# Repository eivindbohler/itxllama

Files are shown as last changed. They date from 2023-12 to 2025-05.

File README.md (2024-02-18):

# ITX-Llama User's Guide
  
> **Note**  
> This document is still a work in progress.  
For feedback, suggestions, etc. - please add a post to the [Vogons thread][vogons-thread].

### Contents
- [Installing the SOM](#installing-the-som)
- [Jumper Configuration](#jumper-configuration)
  * [PS/2 and USB HID](#ps2-or-usb-hid)
  * [Line In](#line-in)
  * [Pi or Wavetable](#pi-or-wavetable)
- [Flashing the BIOS](#flashing-the-bios)
- [DOS](#dos)
  * [Mouse in DOS](#mouse-in-dos)
  * [Audio in DOS](#audio-in-dos)
- [Windows 98](#windows-98)
- [Windows 98 Drivers](#windows-98-drivers)
  * [TBPlus](#tbplus)
  * [USB](#usb)
  * [Crystal Audio](#crystal-audio)
  * [Ethernet](#ethernet)
- [Fans](#fans)
- [mt32-pi](#mt32-pi)

## Installing the SOM
When installing the Vortex86EX SOM, _carefully_ align the module as shown in the image below, and _gently_ push it down on the 64 pins.  
Note that the pins on the motherboard are quite thin and fragile, and if you misalign the SOM or use excessive force, they'll likely bend or break.  
Take your time, be careful and double-check the placement before proceeding further!
<p>
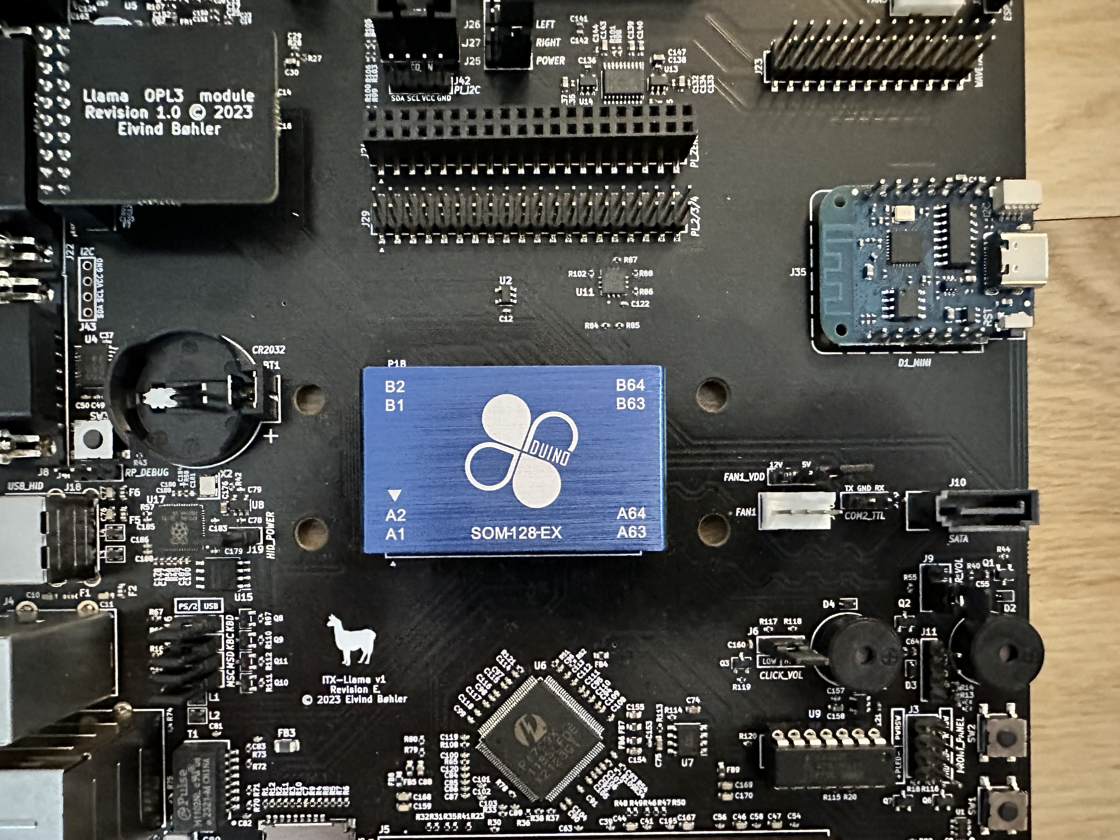
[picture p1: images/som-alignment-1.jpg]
SOM alignment
  
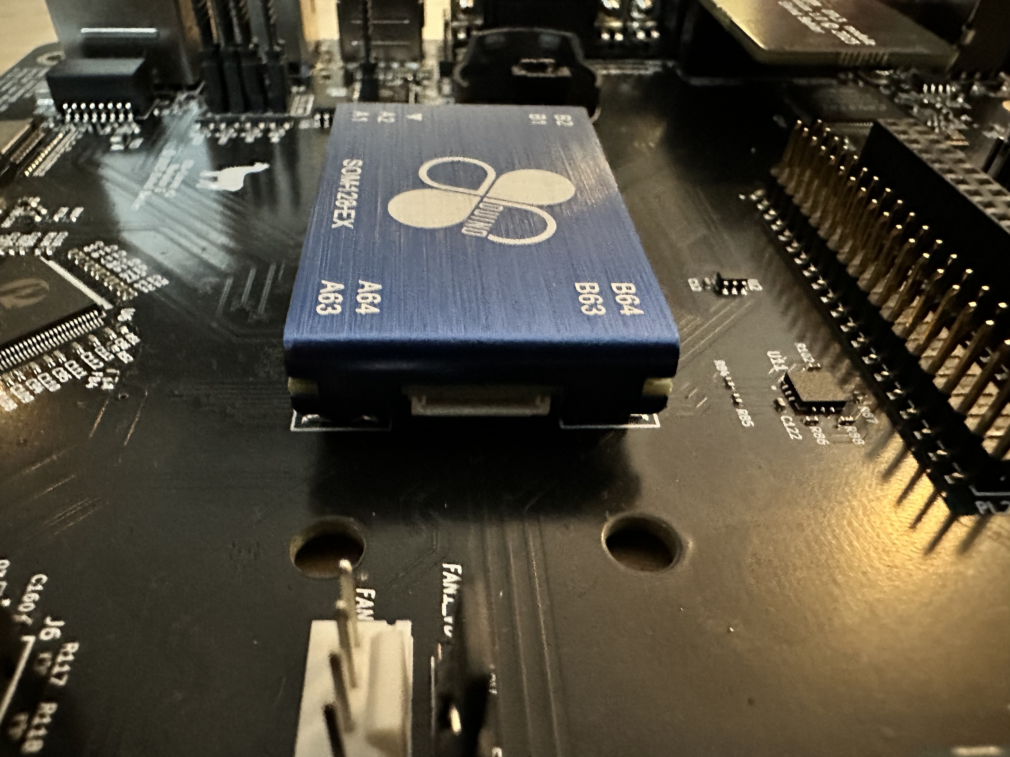
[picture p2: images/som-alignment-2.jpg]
SOM alignment
  
</p>

## Jumper Configuration
The board should come preinstalled with all the jumpers necessary.  
For changing the configuration, here's a quick walkthrough of the different jumpers and their functionality.

### PS/2 or USB HID
Jumpers: J7, J12, J15, J16
<p>
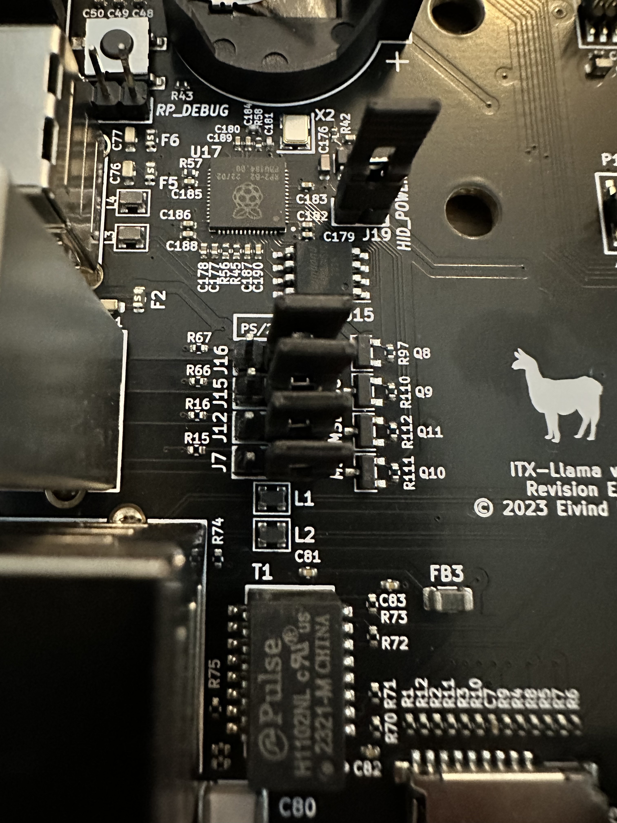
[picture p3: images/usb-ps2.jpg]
PS/2 configuration
  
</p>
If you want to use a real PS/2 keyboard connected to the purple PS/2 port, place the two topmost jumpers (J15 and J16) to the leftmost position ("PS/2"). For USB HID keyboard connected to one of the white USB ports (between the PS/2 and serial port), place the jumpers to the rightmost side ("USB").  
Same goes for PS/2 mouse and jumpers J7 and J12.

### Line In
Jumpers: J39, J40
<p>
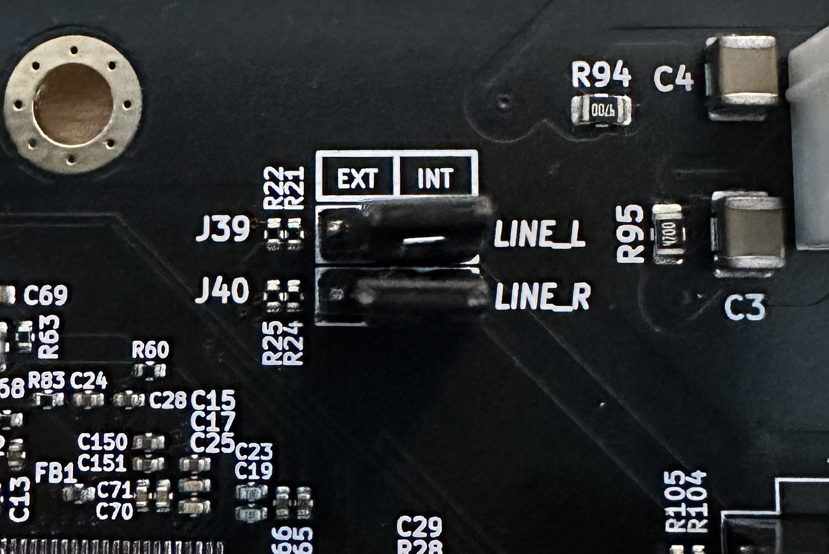
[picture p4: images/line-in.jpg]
Line In
  
</p>
If you want to use an external audio source connected to the blue 3.5mm jack port, place both jumpers to the leftmost position ("EXT").  
For using a Raspberry Pi Zero2 or Wavetable board as line-in to the sound card, place the two jumpers to the rightmost position ("INT").

### Pi or Wavetable
Jumpers: J25, J26, J27
<p>
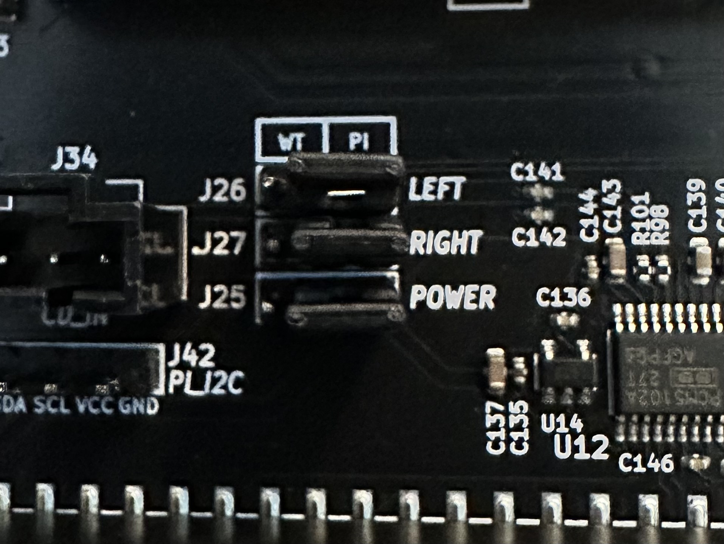
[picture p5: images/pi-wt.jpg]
PI/WT configuration
  
</p>
For using a Raspberry Pi (Zero2, 3 or 4) for converting MIDI to analog audio, place the three jumpers to the rightmost position ("PI").  
For using a wavetable board, place the jumpers to the leftmost position ("WT").

## Flashing the BIOS
If you've purchased the Vortex86EX system-on-module (SOM) from DMP, ICOP, etc - you need to flash the BIOS first.  
Since the BIOS that comes pre-installed on the SOM is set up for another pinout/configuration, the microSD card slot isn't availble yet, and you need to use a USB flash drive for this part.  
  
Format the flash drive with a DOS-bootable FAT16/32 partition and copy over the [ANYBIOS.EXE and ITXBIOS.ROM files](INITBIOS).  
Alternatively (and easier), just do a block-level transfer of the [INITBIOS.IMG](INITBIOS) file to the flash drive using [Balena Etcher][balena-etcher], `dd` or something similar.  
Then place the flash drive in one of the USB ports (the ones below the RJ45 port). Plug a USB keyboard in the other port. **Note**: at this point, a keyboard plugged into one of the two _HID-only (white)_ ports won't work, you need to use the ones below the RJ45 port!  
Power up the system, and hopefully you'll get a DOS prompt. From there just type:
```
anybios w itxbios.rom
```
Once done, shut down the computer, remove the flash drive and move the keyboard to one of the HID ports.

## DOS
Follow these instructions to set up DOS on a microSD card, SATA drive or USB flash drive:  
(Note: a SATA drive is faster, but this isn't that important in DOS. I recommend using a microSD card, because you'll be able to use the "clicker" feature to simulate the seeking sounds of an old spinning drive, if you're interested in that)
1. Turn off the system, insert a drive of choice.
2. Boot the system, press ESC to bring up the boot menu.
3. Choose the Virtual Floppy drive.
4. Run `fdisk`, select and partition the drive however you want. Make sure to have at least one primary partition, and make it `Active`.
5. Quit fdisk and reboot the system.
6. Once again, boot the system using the Virtual Floppy drive.
7. Run `fdisk /mbr` to write the correct MBR bytes to the new drive.
8. Run `format c: /s` to format the new drive and copy over the necessary system files.
9. Shut down the machine and remove the drive.
10. Copy over DOS and whatever else you want from a modern computer.

### Mouse in DOS
Use [CuteMouse (CTMOUSE.EXE)](DOS-utils).

### Audio in DOS
The Crystal CS4237B sound chip is automatically initialized and configured from the BIOS, so you don't need any drivers in DOS.  
If you wish to change any of the mixer settings, use [CWDMIX.EXE](DOS-Utils).

## Windows 98
Before proceeding, I'd _strongly_ recommend using a SATA drive for Windows 98, as the performance is noticably better than running from an SD card or USB drive.  
  
Download Windows 98 SE from [WinWorldPC][winworldpc-win98]. Product keys are there as well.  
  
Prepare a bootable DOS drive (see the [DOS](#dos) section above), copy the `WIN98` folder over to the drive and run the `SETUP.EXE` from within.

Note: at some point during the installation, you'll get a crash. This is due to the IDE driver being incompatible with the Vortex86EX's IDE controller.  
Reboot, and choose "Safe Mode". From within Win98, install the [TBPLUS](WIN98-drivers/TBPLUS) drivers from R. Loew and then reboot again and complete the installation.  
  
An easier way is to install Windows 98 SE is using a [version I've prepared](WIN98) which has the IDE drivers "slipstreamed" (meaning that Windows will use the updated drivers automatically).

## Windows 98 Drivers

### TBPlus
If you installed the TBPlus drivers during the Windows 98 installation, or used the slipstreamed Windows 98 installer you're all set. If not, install the [TBPlus drivers](WIN98-drivers/TBPLUS).

### USB
In the BIOS Settings, you can choose to have USB flash drives appear to the system as fixed disks.  
With this setting enabled, they'll show up as regular hard drives in DOS and Windows.  
If you turn this setting _off_, you can use flash drives as removable storage in Windows 98. Use [nusb36e.exe](WIN98-drivers/USB) to install the required drivers.

### Crystal Audio
Run `SETUP.EXE` from the [Crystal Audio](WIN98-drivers/CWD-v286-1998-itx-llama) driver folder.

### Ethernet
From Device Manager, find the Ethernet device and install the [RDC R6040 driver](WIN98-drivers/r6040_win98).

## Fans
The Vortex86EX SOM doesn't draw much power, and shouldn't require active cooling if running at or below 300 MHz.  
If you do wish to add one or more fans, the motherboard has three separately controllable 4-pin PWM fan connectors:
<p>
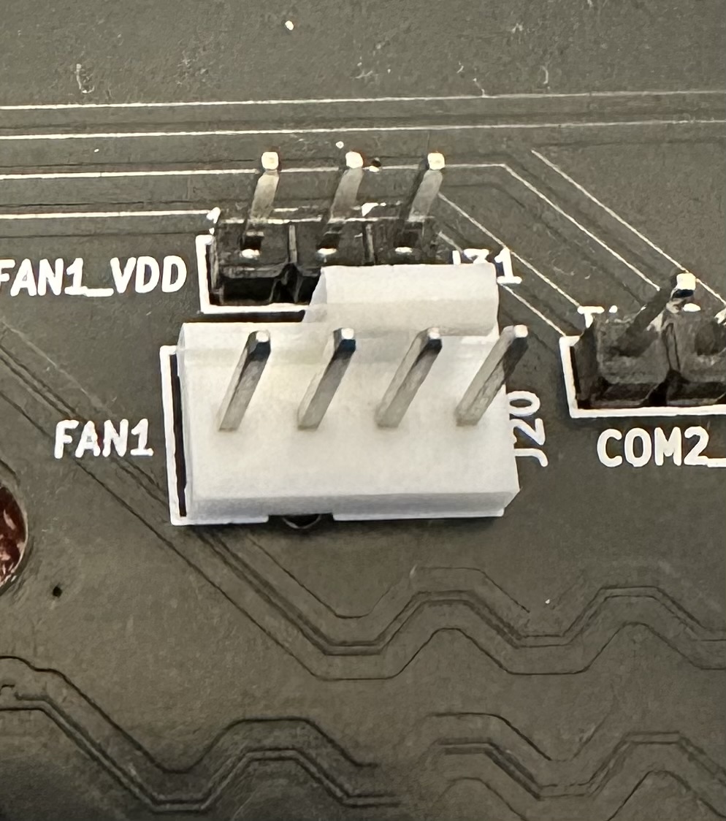
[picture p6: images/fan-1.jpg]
Fan header
  
</p>
Simply connect a modern 4-pin fan to one of these headers, and set the corresponding jumper to either 5V or 12V:
<p>
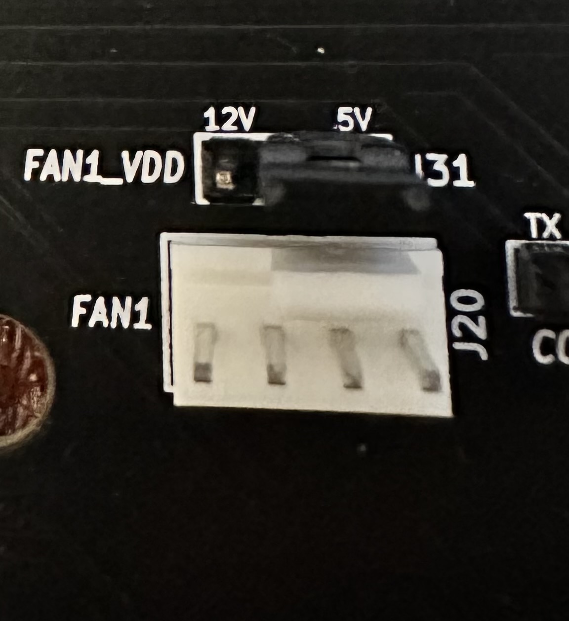
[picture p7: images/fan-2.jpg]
Fan configuration
  
</p>

Note: Take care **not** to supply 12V to a 5V fan - you'll likely fry it.

## mt32-pi
If you want to use a Raspberry Pi as an MT-32 or MIDI synthesizer, download and install the [mt32-pi][mt32-pi] bare-metal software on the Pi, and plug it into the motherboard.  
If you go with a Pi Zero 2 (the easiest and cheapest option), make sure to solder the 40-pin connector to the _bottom_ side of the Pi, as seen here:
<p>
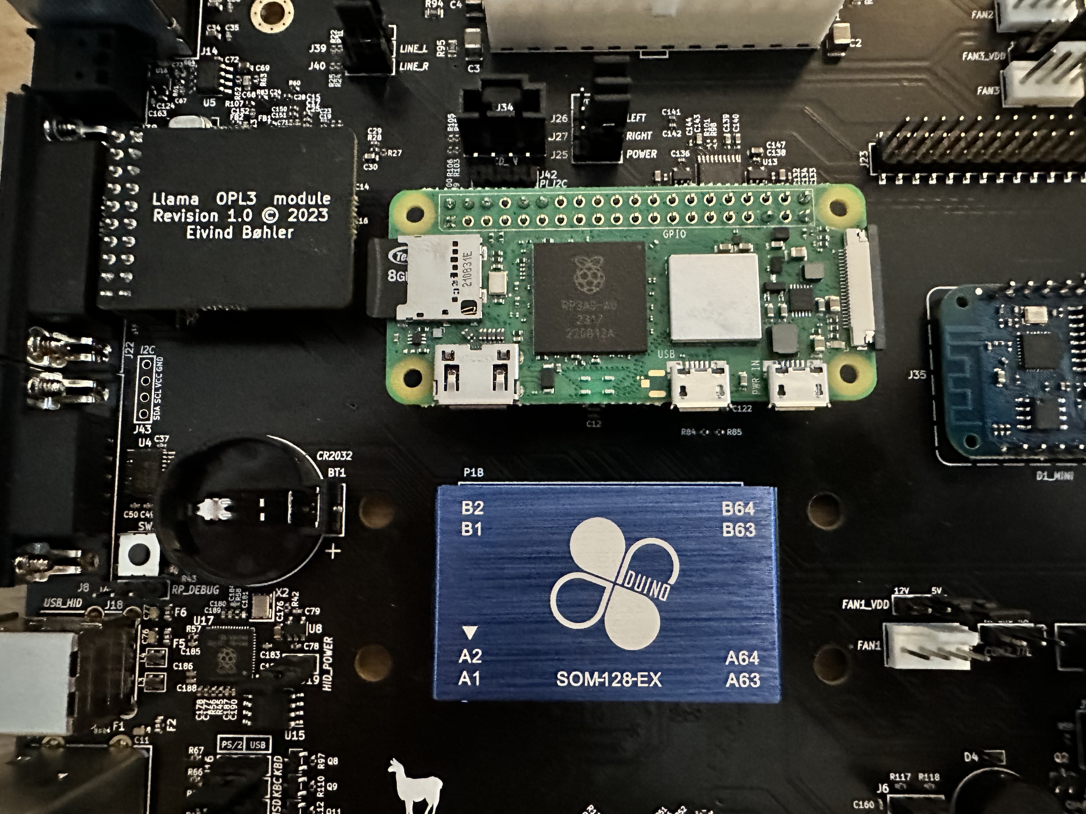
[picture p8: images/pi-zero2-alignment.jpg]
Pi Zero 2 alignment
  
</p>

Look at the [mt32-pi github page][mt32-pi] for setup, configuration options etc.  
As a minimum, you want to set the output of the mt32-pi as type "i2s":
```
output_device = i2s
```  
Use the [mt32-pi-control][mt32-pi-control] software from DOS to switch between MT-32 and MIDI mode.

[balena-etcher]: https://www.balena.io/etcher
[winworldpc-win98]: https://winworldpc.com/download/417d71c2-ae18-c39a-11c3-a4e284a2c3a5
[vogons-thread]: https://www.vogons.org/viewtopic.php?t=93480
[mt32-pi]: https://github.com/dwhinham/mt32-pi
[mt32-pi-control]: https://github.com/gmcn42/mt32-pi-control/tree/main/dos_bin

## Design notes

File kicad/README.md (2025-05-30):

### Notice:
This folder contains all files necessary to produce the ITX-Llama board from JLCPCB, or to continue development of the board.  
However, I don't give any guarantees that everything is correct and working; you need to have a good understanding of Kicad and the PCB/assembly ordering process - and check everything yourself.

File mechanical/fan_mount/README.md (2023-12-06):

### Fan mount 3D models
These STEP files are made specifically for the 40x40x10mm Noctua fan, and should be 3D-printed using a rather small layer height to make sure the threads are sufficiently detailed.
<p>
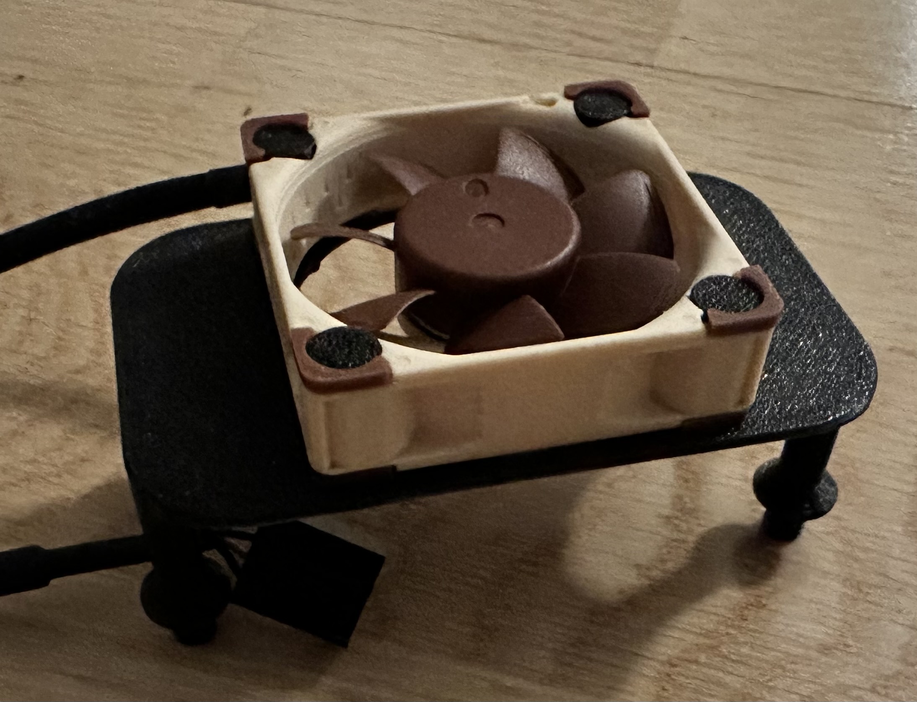
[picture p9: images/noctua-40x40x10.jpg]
SOM alignment
  
</p>

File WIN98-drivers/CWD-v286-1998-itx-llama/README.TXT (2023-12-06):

************************************************************************
                          Release Notes for
                 Crystal SoundFusion Audio Driver Kit
************************************************************************
          (c) 2001 by Cirrus Logic, Inc. All rights reserved.

------------------------------------------------------------------------
Release name         PV2860
Release date         6/5/99
Driver style         VxD
Operating systems    Windows 95 and 98 (initial release)
Language             Multicountry
------------------------------------------------------------------------

========================================================================
Contents
========================================================================

1. Hardware Requirements
2. Features 
3. Fixes
4. Installing the Driver
5. Uninstalling the Driver
6. Known Incompatibilities and Limitations
7. Copyrights

========================================================================
1. Hardware Requirements
========================================================================

This audio driver is designed to work with the following: 

			CS4232
			CS4235
			CS4236B
			CS4237B
			CS4238B
			CS4239

========================================================================
2. Features 
========================================================================

========================================================================
3. Fixes
========================================================================

========================================================================
4. Installing the Driver
========================================================================
 
    WINDOWS 95

    1.	Windows95 will detect the PCI Multimedia Audio device.  Press the NEXT 
        button. 

    2.  The driver for the "Crystal SoundFusion (tm) PCI Audio Accelerator 
	Driver.  will be requested by the Operating System. Enter the drive 
	letter assigned to your CDROM or press the BROWSE button and search 
	for the CDROM Drive or the location of the driver files. Once the 
	path has been provided, press the FINISH button.

    3.	Again, Windows95 will request that you provide the Crystal 
	SoundFusion(tm) Disk.  Press the OK button to continue, then 
	provide the path to the location of the driver files.

    WINDOWS 98

    1.  Windows will detect the PCI Multimedia Audio Device and initiate the 
        Add New Hardware Wizard.  Press the NEXT button to continue.

    2.  Select the 'Search for the best driver for your device' option and press
        the NEXT button.

    3.  Select the CD-ROM drive (or the appropriate path to the location of 
        the driver files).  Press the NEXT button.

    4.  The installation wizard will indicate that it is ready to install the 
        Crystal SoundFusion (tm) PCI Audio Accelerator Driver.  Press the NEXT 
	button to 6:24 PM 5/14/99continue.
    
    5.  Press the FINISH button to complete the installation.

========================================================================
5.  Uninstalling or Updating Crystal Audio Drivers
========================================================================

    1. 	From the Windows START menu, run SETUP.EXE located in the Crystal 
        SoundFusion(tm) CD (or the appropriate path to the location of 
        the driver files) and select Install or Uninstall.  This application 
        will do an automatic clean-up of the Windows 95 Crystal Audio registry 
        entries.  
        
        NOTE: Many problems with reinstallation occur because of existing 
        registry entries from previous installations and because of the 
        \WINDOWS\INF\OEMx.INF files.  After running SETUP.EXE, the various 
        Crystal devices should not be listed in the Device Manager window.  

    2. 	Restart your system.  If you want to remove or install any hardware, 
	select the SHUTDOWN option and turn off your PC.

    3.	Turn PC on.  Upon loading, Windows 95 will detect new hardware, create 
	an information database, and proceed with the installation of Crystal 
	device drivers (as described in the previous section)

========================================================================
6.  Known Incompatibilities and Limitations
========================================================================

========================================================================
7.  Copyright and Trademarks
========================================================================

    * All brands and product names noted herein are the property or trademarks
      of their respective holders.
--------------------------------------------------------------------------------
                                                             Cirrus Logic, 2001
--------------------------------------------------------------------------------

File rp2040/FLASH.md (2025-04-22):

# Flash

How to update the RP2040 USB to PS/2 converter on the ITX-Llama:

You will need a USB-A to USB-A cable and another PC or Mac.

1. remove the jumper **J19** HID_POWER
2. hold down the button **SW3** between the white USB ports and the CMOS battery
3. while holding **SW3** connect another PC or Mac to the **lower white USB port**
4. a flash drive named **RPI-RP2** appears, drag the latest release file onto it: [itxllama-rp2040.uf2](https://github.com/eivindbohler/itxllama/raw/refs/heads/main/rp2040/build/itxllama-rp2040.uf2)
5. disconnect the USB cable
6. reinstall the jumper **J19** HID_POWER
<p>
  PS/2 configuration
</p>

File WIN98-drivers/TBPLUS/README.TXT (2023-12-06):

             INSTALLATION INSTRUCTIONS FOR TBPLUS PATCH PACKAGE

                             Version 3.0

                              11/02/2015

                        Copyright (C) 2010-2015
                          By Rudolph R. Loew

This Package contains the Patched System Files and SATA INF Files to support
the following features.

1. Large Sector Size support up to 32KB per Sector in DOS.
2. Large Sector Size support up to 4KB per Sector in Windows 98SE.
3. 256 Sector (128KB to 1MB/8MB) Cluster Size support for DOS and Windows.
4. Full 48-Bit LBA Addressing Support for Windows 98SE.
5. Support for 40-Bit Partition Addresses (RFDISK ExtMBR Feature).
6. Boot DOS using any or all above Features.
7. Patched Partitioning bug when using Multiple Primary Partitions.
8. Support for Multiple Extended Partitions.
9. Support for Large Sector Floppy Disks.
10. Native Mode support for SATA Controllers for Windows 98SE.
11. Support for 64-Bit Addressing for SCSI and USB.
12. Generic Drivers for RAID and RAID/AHCI SATA/PATA Controllers.
13. Driver for SI 3512 SATA Controller.
14. Windows Only Partitions.

The Patch files are based on the most recent Versions of the Windows 98SE
files for the English Version, except DISKTSD which is upgraded to the
Windows ME Version.

INSTALLATION

To Install the full Package run the INSTALL.BAT Script using the following
Syntax:

INSTALL [[WinDir] WinBootDir]

Where "WinDir" is the Path to the Windows Folder (ex. C:\WINDOWS).
Where "WinBootDir" is the Path to the Windows Boot Folder (ex. C:\WIN98) if
 running Windows 98 not 98SE.
These arguments are optional if running from a DOS Box in Windows.

If you have an early VIA Controller that does not support AHCI and you plan
to set it to RAID Mode, remove the WINDOWS\INF\ATA0104A.INF File. Otherwise
remove the WINDOWS\INF\ATA0104.INF File.

If you have an early VIA Controller and you plan to set it to IDE Mode, run
the PATCHPCI Porgram to prevent a possible hang.

UNINSTALL

To Uninstall the full Package run the UNINST.BAT Script using the following
Syntax:

UNINST [[WinDir] WinBootDir]

Where "WinDir" is the Path to the Windows Folder (ex. C:\WINDOWS).
Where "WinBootDir" is the Path to the Windows Boot Folder (ex. C:\WIN98) if
 running Windows 98 not 98SE.
These arguments are optional if running from a DOS Box in Windows.

If you ran PATCHPCI during Install, rerun it to Uninstall the Patch.

PARTIAL INSTALLATIONS

To Install or Uninstall only the Windows Patches use:

INSTALLW [WinDir]
or
UNINSTW [WinDir]

Where "WinDir" is the Path to the Windows Folder (ex. C:\WINDOWS).
This argument is optional if running from a DOS Box in Windows.

Follow instructions relating to VIA Controllers in INSTALL Section above.

To Install or Uninstall only the DOS Patches use:

INSTALLD [[DOSDir] BOOTDir]
or
UNINSTD [[DOSDir] BOOTDir]

Where DOSDir is the Path to the Folder that contains the SMARTDRV.EXE Program.
Where BOOTDir is the Path to the Folder that contains the DBLBUFF.SYS File
 if different.
These arguments are optional if running from a DOS Box in Windows.

You will need to reboot for the Patches to take effect.

IMPORTANT: The DOS ATTRIB.EXE Command must be in the current PATH to update
           IO.SYS for the Full or DOS Patch Installation. Copy the ATTRIB.EXE
           to the current Directory otherwise.

           If you have an AHCI Only SATA Controller in your Computer, you
           must remove the ATA0106.INF File from your WINDOWS\INF Folder after
           you Install the Patch and before you Reboot.

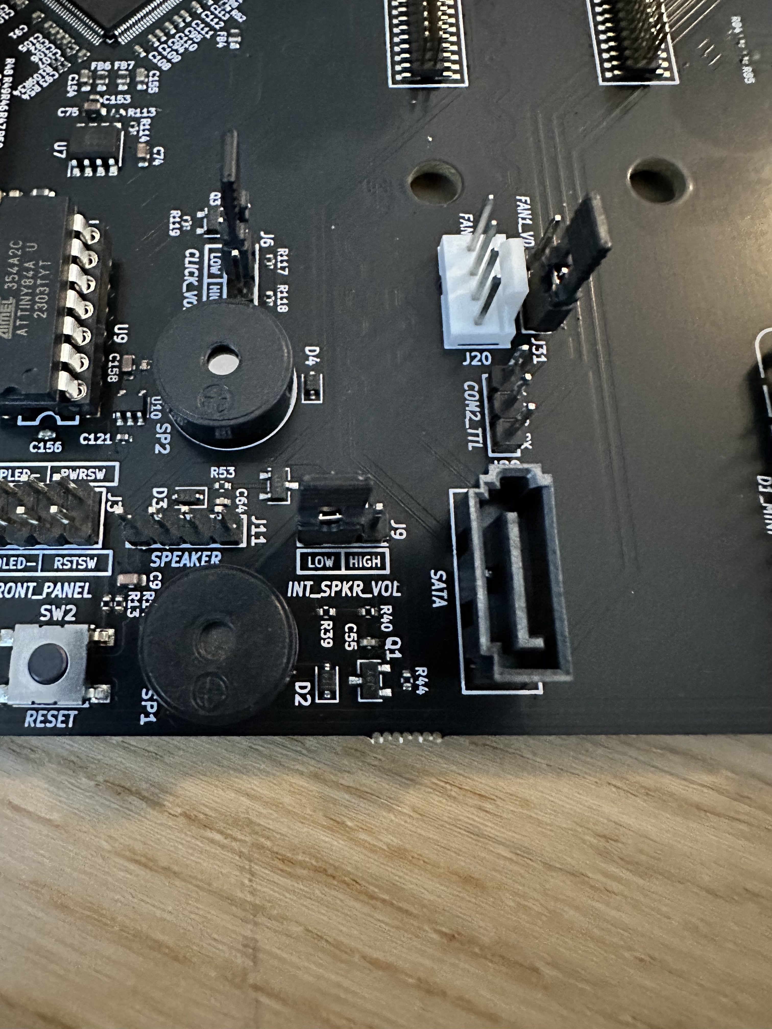
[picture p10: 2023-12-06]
images/int-speaker.jpg

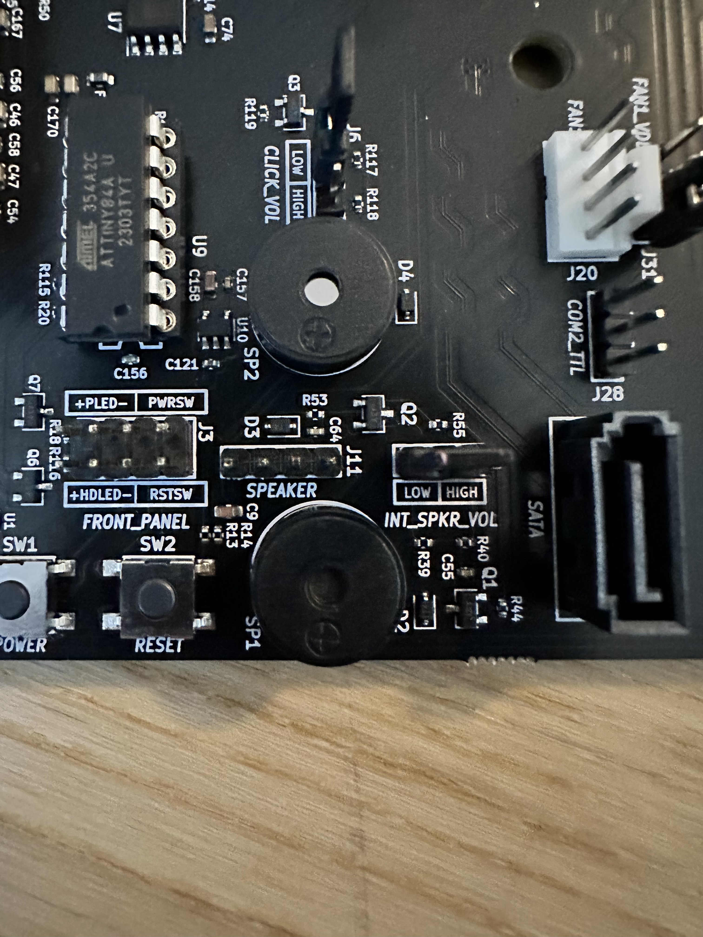
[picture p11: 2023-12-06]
images/speaker.jpg

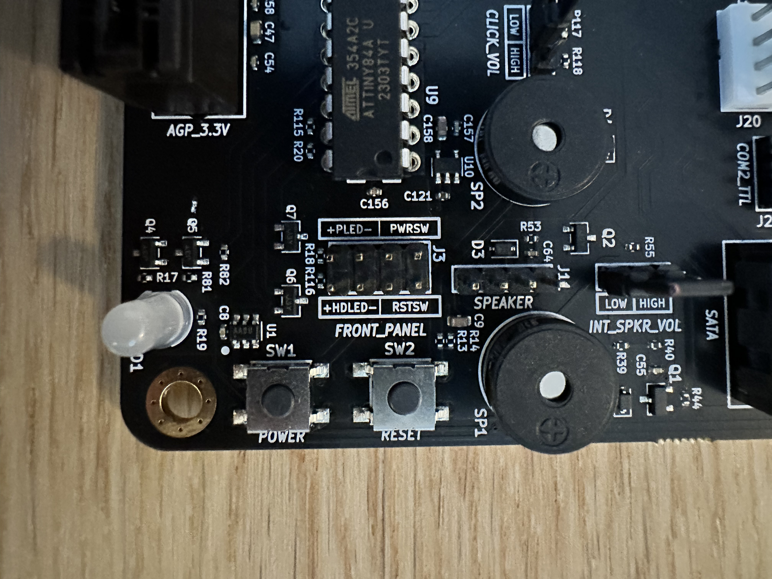
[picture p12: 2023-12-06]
images/front-panel.jpg

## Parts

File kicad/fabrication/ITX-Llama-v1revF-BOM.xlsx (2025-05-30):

Comment | Designator | Qty | Footprint | LCSC
CR2032 | BT1 | 1 | BT_BS-02-A1AJ006 | C964745
100uF | C1,C2,C3,C4 | 4 | C_1210_3225Metric | C90143
5.6nF | C127,C128 | 2 | C_0402_1005Metric | C162195
2.2uF | C139,C140 | 2 | C_0603_1608Metric | C23630
2.2nF | C141,C142 | 2 | C_0402_1005Metric | C1531
1uF | C15,C24,C28,C65,C66,C67,C78,C121,C132,C135,C150,C151,C152,C177,C178 | 15 | C_0402_1005Metric | C77009
30pF | C180,C181 | 2 | C_0402_1005Metric | C107004
1nF | C19,C23,C35,C36,C125,C126 | 6 | C_0402_1005Metric | C76947
22pF | C20,C21 | 2 | C_0402_1005Metric | C76960
2.7nF | C30,C68 | 2 | C_0603_1608Metric | C326881
330pF | C48,C49,C50 | 3 | C_0402_1005Metric | C106206
47uF | C5,C10,C11,C27,C31,C32,C43,C44,C45,C46,C47,C53,C61,C62,C76,C77,C159,C161,C167,C168,C169,C170,C171,C173 | 24 | C_0603_1608Metric | C140782
10nF | C55,C64,C160 | 3 | C_0402_1005Metric | C60133
0.1uF | C6,C7,C8,C12,C13,C14,C16,C17,C18,C22,C25,C26,C29,C37,C38,C39,C40,C41,C42,C51,C54,C56,C57,C58,C59,C60,C63,C72,C73,C81,C82,C83,C84,C85,C86,C87,C89,C90,C91,C92,C93,C94,C95,C96,C97,C98,C99,C100,C101,C102,C103,C104,C105,C106,C107,C108,C109,C110,C111,C112,C113,C114,C115,C116,C117,C118,C119,C120,C122,C123,C124,C129,C130,C131,C138,C144,C145,C146,C153,C156,C162,C163,C164,C165,C166,C179,C182,C183,C184,C185,C186,C187,C188,C189,C190 | 95 | C_0402_1005Metric | C1525
0.33uF | C70,C71 | 2 | C_0402_1005Metric | C107013
470pF | C79,C133,C136,C157 | 4 | C_0402_1005Metric | C106207
1nF | C80 | 1 | C_1812_4532Metric | C106132
4.7uF | C88,C154,C155 | 3 | C_0603_1608Metric | C1705
10uF | C9,C33,C34,C52,C69,C74,C75,C134,C137,C143,C147,C148,C149,C158,C172,C174,C175,C176 | 18 | C_0603_1608Metric | C344022
RGB_LED | D1 | 1 | D_LED_D5.0mm-4_RGB | C331057
1N4148 | D2,D3,D4 | 3 | D_SOD-323F | C2128
F | F1,F2,F3,F4,F5,F6,F7 | 7 | Fuse_0603_1608Metric | C18203128
600Ω@100MHz | FB1,FB2 | 2 | R_0402_1005Metric | C160977
50Ω@100MHz | FB3 | 1 | R_1206_3216Metric | C668307
70Ω@100MHz | FB4,FB5,FB6,FB7 | 4 | R_0603_1608Metric | C113031
ATX_POWER | J1 | 1 | J_ATX_5.5mm | C114088
SATA | J10 | 1 | J_SATA | C2926809
2.54mm PH 1x4 | J11 | 1 | P_CONN_01X04 | C492403
2.54mm PH 1x9 | J42 | 1 | P_CONN_01X09 | C2894932
2.54mm PH 1x5 | J13 | 1 | P_CONN_01X05 | C6332198
AUDIO | J14 | 1 | J_AUDIO_ABA-JAK-027-K24 | C962118
USB_ETH | J17 | 1 | J_USB_A_ETH_C3000093 | C3000093
USB_HID | J18 | 1 | J_USB_A_C456021 | C456021
2.54mm PH 1x2 | J19,J36 | 2 | P_CONN_01X02 | C358684
MICRO_SD | J2 | 1 | J_MicroSD_TF01A | C91145
FAN | J20,J21,J30 | 3 | J_MOLEX_47053-1000 | C240840
GAMEPORT | J22 | 1 | J_DA15 | C77835
WAVETABLE | J23 | 1 | J_CONN_WAVETABLE | C2884022
PI_ZERO2 | J24 | 1 | J_CONN_RPI_SMD | C3975165
PI_2/3/4 | J29 | 1 | J_CONN_RPI_SMD_PI3 | C2884029
FRONT_PANEL | J3 | 1 | P_CONN_PANEL | C492421
CD_IN | J34 | 1 | J_CONN_CD_AUDIO | C41927
D1_MINI | J35A,J35B | 2 | J_CONN_D1_MINI | C27438
J_TOSLINK_ZGY133T10 | J38 | 1 | J_TOSLINK_ZGY133T10 | C2940206
PS/2 | J4 | 1 | J_PS2_KMDGX | C5449250
EXT_SYNTH | J41 | 1 | J_CONN_02X10 | C2685129
2.54mm PS 1x4 | J43 | 1 | J_CONN_01X04 | C2718488
AGP_3.3V | J5 | 1 | J_TE_5145263-3 | C4924602
2.54mm PH 1x3 | J6,J7,J9,J12,J15,J16,J26,J27,J28,J31,J32,J33,J39,J40,J46 | 15 | P_CONN_01X03 | C49257
COM1 | J8 | 1 | J_DE9M | C141880
L_EMI_FILTER | L1,L2,L3,L4 | 4 | L_EMI_FILTER_MCM2012B900GBE | C315725
P_SOM-128-EX | P1A,P1B | 2 | P_CONN_SOM-128-EX_FAN | C2881937
NPN | Q1,Q2,Q3,Q4,Q5,Q6,Q7 | 7 | Q_BJT_SOT-23-3 | C2146
NMOS | Q8,Q9,Q10,Q11 | 4 | Q_NMOS_SOT-23-3 | C5224263
47k | R1,R2,R3,R4,R5,R6,R27,R60,R61 | 9 | R_0402_1005Metric | C93943
0 | R10 | 1 | R_0402_1005Metric | C60485
22 | R109 | 1 | R_0402_1005Metric | C25092
15.8k | R113 | 1 | R_0402_1005Metric | C26956
36k | R114 | 1 | R_0402_1005Metric | C852742
10k | R13,R20,R42,R57,R81,R82,R87,R88,R97,R100,R102,R110,R111,R112,R115,R120 | 16 | R_0402_1005Metric | C60490
470 | R14,R98,R101 | 3 | R_0402_1005Metric | C227095
4.7k | R15,R16,R28,R62,R66,R67,R84,R85,R86,R89,R90,R91 | 12 | R_0402_1005Metric | C105871
600 | R17,R63 | 2 | R_0402_1005Metric | C8369
330 | R18,R74,R75,R116 | 4 | R_0402_1005Metric | C105875
2k | R19,R64 | 2 | R_0402_1005Metric | C60488
6.8k | R21,R22,R24,R25,R103,R104,R105,R106 | 8 | R_0402_1005Metric | C93940
5.1k | R23,R26,R29,R30,R31,R32,R33,R34,R35,R36,R37,R38,R41,R46,R47,R48,R49,R50,R51,R52,R54,R79,R80,R108,R121 | 25 | R_0402_1005Metric | C105872
200 | R39,R117 | 2 | R_0402_1005Metric | C784580
1k | R43,R44,R55,R58,R78,R119 | 6 | R_0402_1005Metric | C11702
27 | R45,R56,R122,R123 | 4 | R_0402_1005Metric | C138021
470 | R59,R94,R95,R96 | 4 | R_0805_2012Metric | C17710
1.43k | R65 | 1 | R_0402_1005Metric | C163483
75 | R68,R69,R76,R77 | 4 | R_0402_1005Metric | C114757
33 | R7,R8,R9,R11,R12,R40,R53,R118 | 8 | R_0402_1005Metric | C25105
49.9 | R70,R71,R72,R73 | 4 | R_0402_1005Metric | C87044
3.4k | R83,R107 | 2 | R_0402_1005Metric | C4940
2.2k | R92,R93 | 2 | R_0402_1005Metric | C114762
20k | R99 | 1 | R_0402_1005Metric | C93942
SPEAKER | SP1,SP2 | 2 | SP | C252917
SWITCH | SW1,SW2,SW3 | 3 | SW_B3FS-1010 | C271750
Pulse_H1102NL | T1 | 1 | T_PULSE_H1102NL | C18584
MAX16054 | U1 | 1 | U_TSOT-23-6 | C79401
EMC2303 | U11 | 1 | U_EMC2303 | C621414
PCM5102A | U12 | 1 | U_TSSOP-20_4.4x6.5mm_P0.65mm | C107671
W25Q32JVSS | U15 | 1 | U_SOIC-8_5.23x5.23mm_P1.27mm | C179173
U_74LVC1G126 | U16 | 1 | U_SOT-23-5 | C7834
U_RP2040 | U17 | 1 | U_QFN40P700X700X90-57N | C2040
U_74LVC1G04 | U2 | 1 | U_SOT-23-5 | C7827
U_CS4237B-KQ | U3 | 1 | U_TQFP-100_14x14mm_P0.5mm | C9900149464
GD75232 | U4 | 1 | U_TSSOP-20_4.4x6.5mm_P0.65mm | C543039
U_MC33078 | U5 | 1 | SOIC-8_3.9x4.9mm_P1.27mm | C108206
PI7C9X118SL | U6 | 1 | U_LQFP-128_14x14mm_P0.4mm_EP | C1546923
AP7165 | U7 | 1 | U_Diodes_SO-8EP | C460364
U_MIC5219-3.3YM5 | U8,U10,U13,U14 | 4 | U_SOT-23-5 | C29613
U_ATTINY84A | U9 | 1 | U_DIP-14_W7.62mm | C72126
16.9344MHz | X1 | 1 | X_Crystal_SMD_HC49S-MINI | C4944017
12MHz | X2 | 1 | X_SMD3225 | C9002

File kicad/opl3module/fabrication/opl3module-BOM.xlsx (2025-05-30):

Comment | Designator | Footprint | LCSC
0.1uF | C1,C2,C3,C4,C9,C10,C11,C12,C17,C18,C19,C20,C25,C26,C27,C28,C33,C34,C35,C36,C41,C42,C43,C44 | C_0402_1005Metric | C1525
68pF | C5,C13,C21,C29,C37,C45 | C_0402_1005Metric | C76977
2.7nF | C6,C7,C14,C15,C22,C23,C30,C31,C38,C39,C46,C47 | C_0603_1608Metric | C1625600
10uF | C8,C16,C24,C32,C40,C48 | C_0603_1608Metric | C344022
600Ω@100MHz | FB1,FB2,FB3,FB4,FB5,FB6 | R_0402_1005Metric | C160977
EXT_SYNTH | J1,J2,J3,J4,J5,J6 | P_CONN_02X10 | C492427
33 | R1,R6,R11,R16,R21,R26 | R_0402_1005Metric | C25105
6.8k | R2,R3,R7,R8,R12,R13,R17,R18,R22,R23,R27,R28 | R_0402_1005Metric | C93940
8.2k | R4,R5,R9,R10,R14,R15,R19,R20,R24,R25,R29,R30 | R_0402_1005Metric | C138071
YMF262 | U1,U4,U7,U10,U13,U16 | U_SOP-24_8.4x15.5mm_P1.27mm | C9900016870
YAC512 | U2,U5,U8,U11,U14,U17 | U_SOP-16_5.3x10.2mm_P1.27mm | C9900130385
TL074 | U3,U6,U9,U12,U15,U18 | U_TSSOP-14_4.4x5mm_P0.65mm | C6964
14.318MHz | XO1,XO2,XO3,XO4,XO5,XO6 | XO_SMD7050 | C41988065

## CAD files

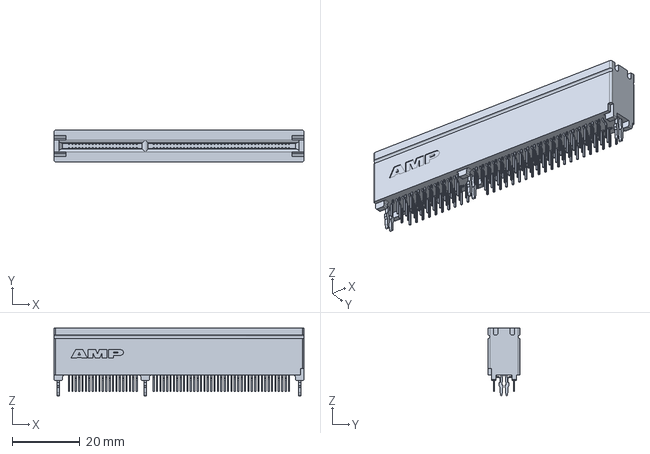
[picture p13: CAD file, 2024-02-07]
kicad/3dmodels/c-5145263-3-a-3d.step
73.9 x 9.40 x 20.0 mm

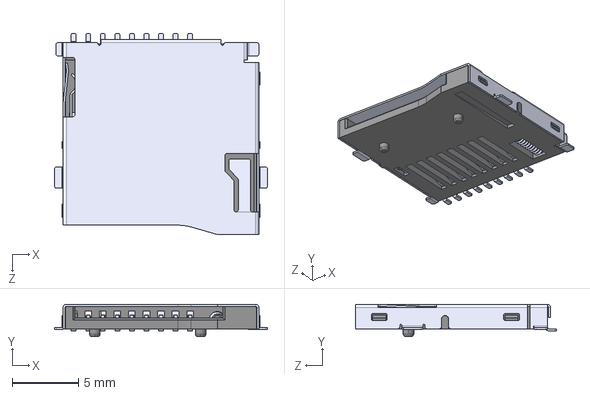
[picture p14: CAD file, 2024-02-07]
kicad/3dmodels/TF-01A--3DModel-STEP-56544.STEP
16.1 x 2.45 x 15.2 mm

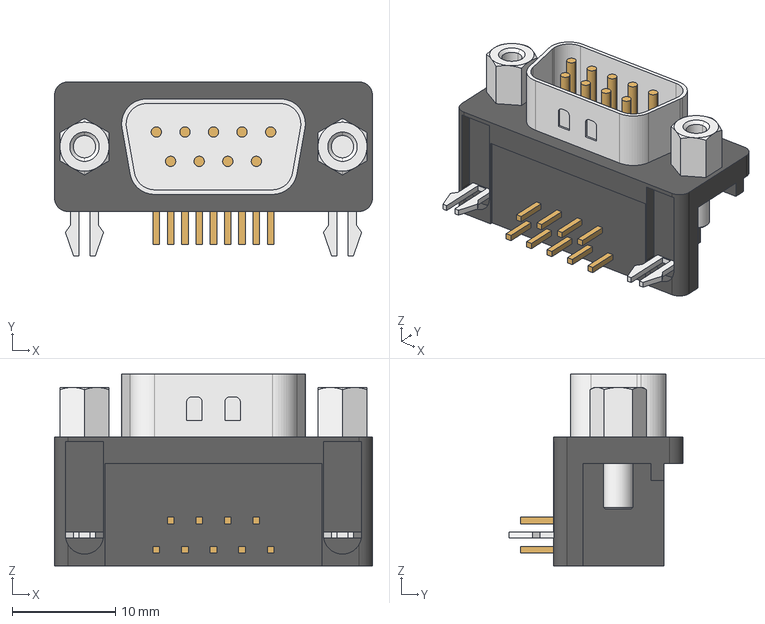
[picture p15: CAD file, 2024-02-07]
kicad/3dmodels/connector_a-ds_09_a_kg-t2.step
30.8 x 16.9 x 18.6 mm

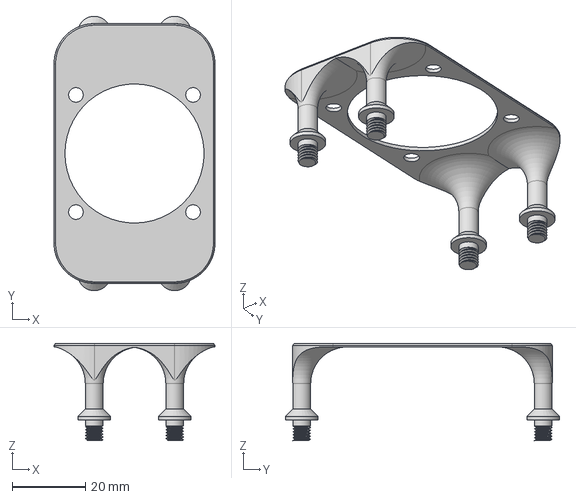
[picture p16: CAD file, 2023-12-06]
mechanical/fan_mount/fan_mount_frame.step
44.0 x 75.0 x 26.6 mm

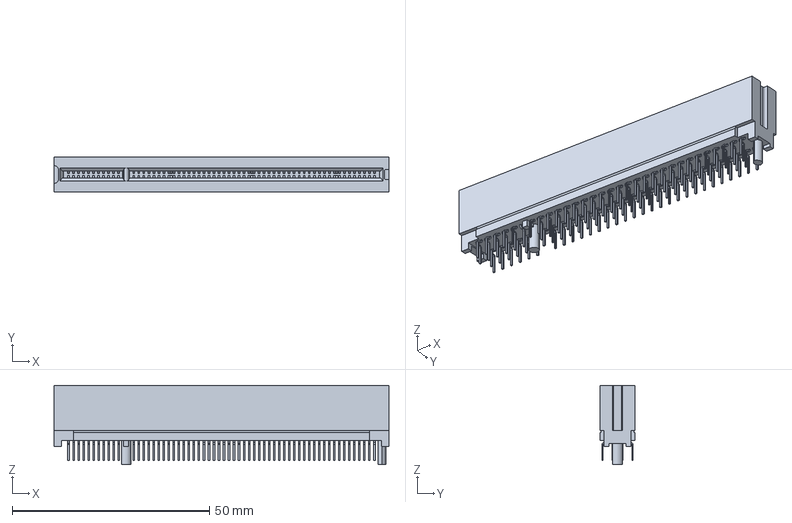
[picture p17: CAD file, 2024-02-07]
kicad/3dmodels/1-5145154-2.step
84.8 x 8.89 x 20.1 mm

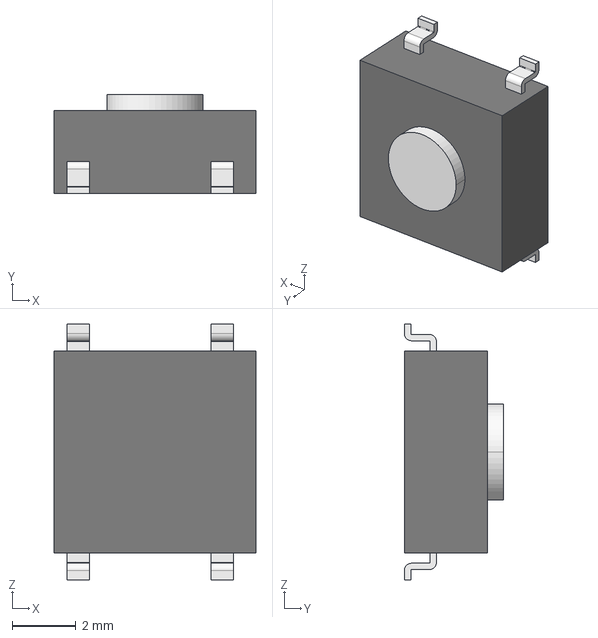
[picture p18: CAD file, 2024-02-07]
kicad/3dmodels/b3fs-1000p.stp
6.30 x 3.10 x 8.00 mm

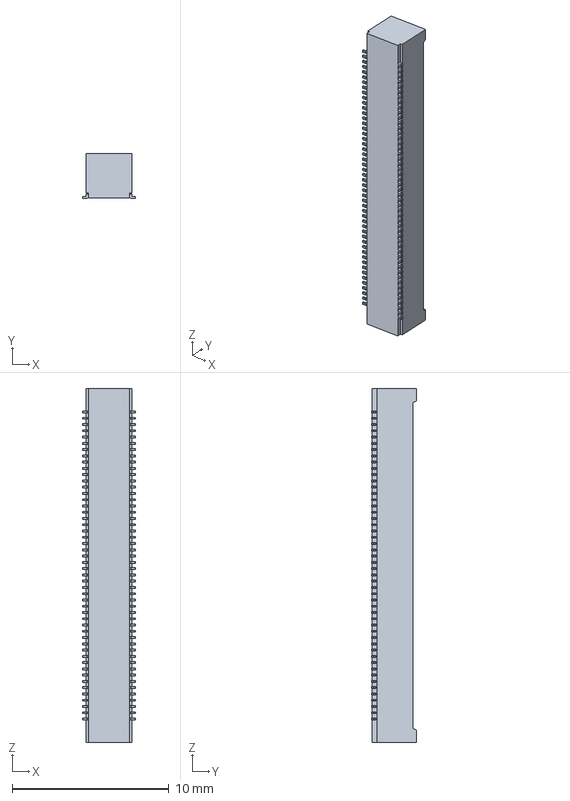
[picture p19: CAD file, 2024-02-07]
kicad/3dmodels/DF40HC-3.0--100DS-0.4V.step
3.38 x 2.90 x 22.6 mm

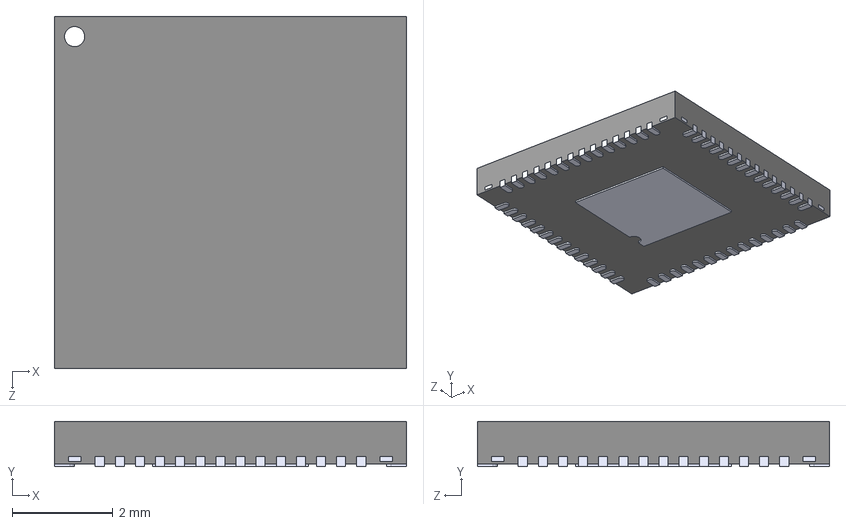
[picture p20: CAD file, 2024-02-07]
kicad/3dmodels/RP2040.step
7.00 x 0.9 x 7.00 mm

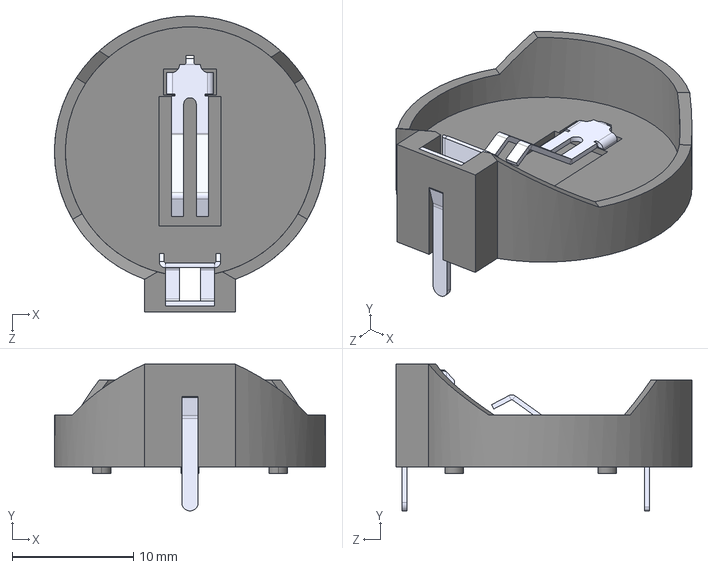
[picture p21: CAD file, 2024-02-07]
kicad/3dmodels/BS-7--3DModel.step
22.3 x 12.1 x 24.4 mm

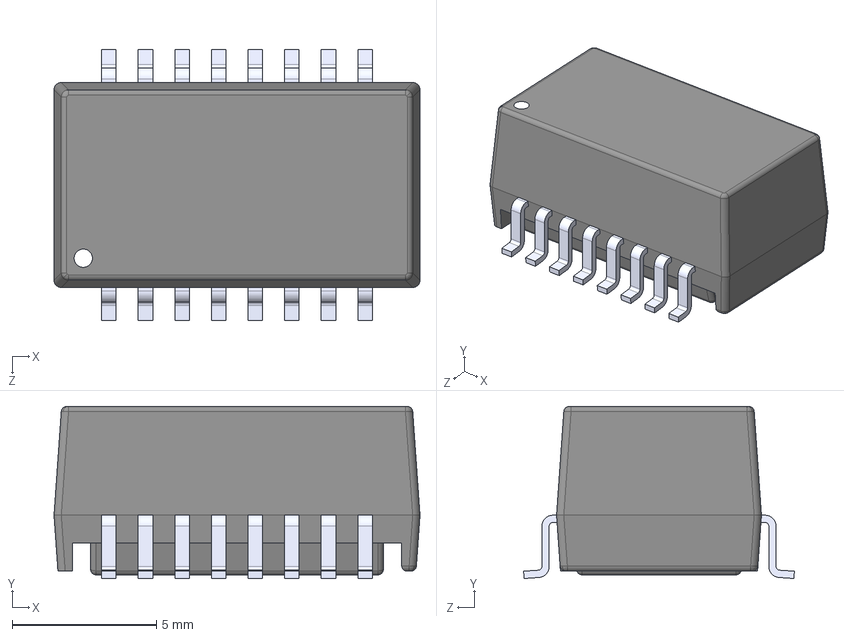
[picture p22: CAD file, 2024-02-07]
kicad/3dmodels/H1102NL--3DModel-STEP-269445.STEP
12.7 x 5.97 x 9.40 mm

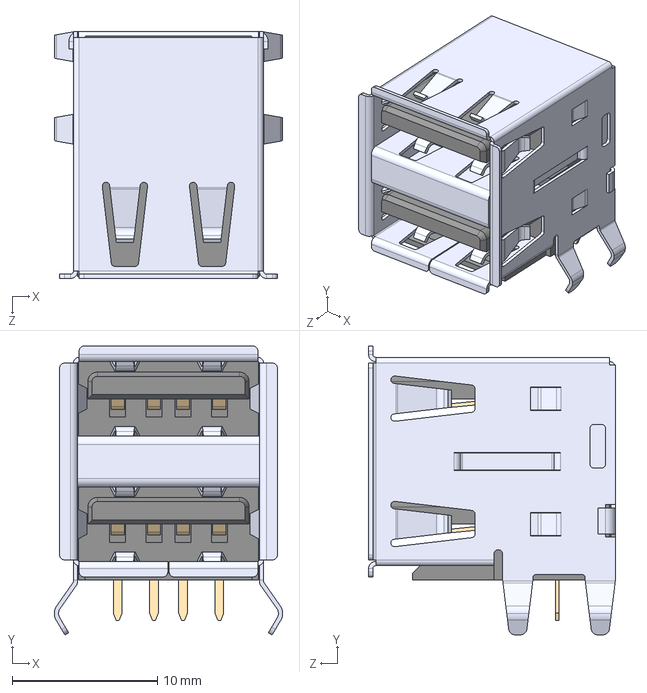
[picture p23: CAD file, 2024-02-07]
kicad/3dmodels/USB1035-GF-P-0-B-B--3DModel-STEP-269445.STEP
15.7 x 19.9 x 17.0 mm

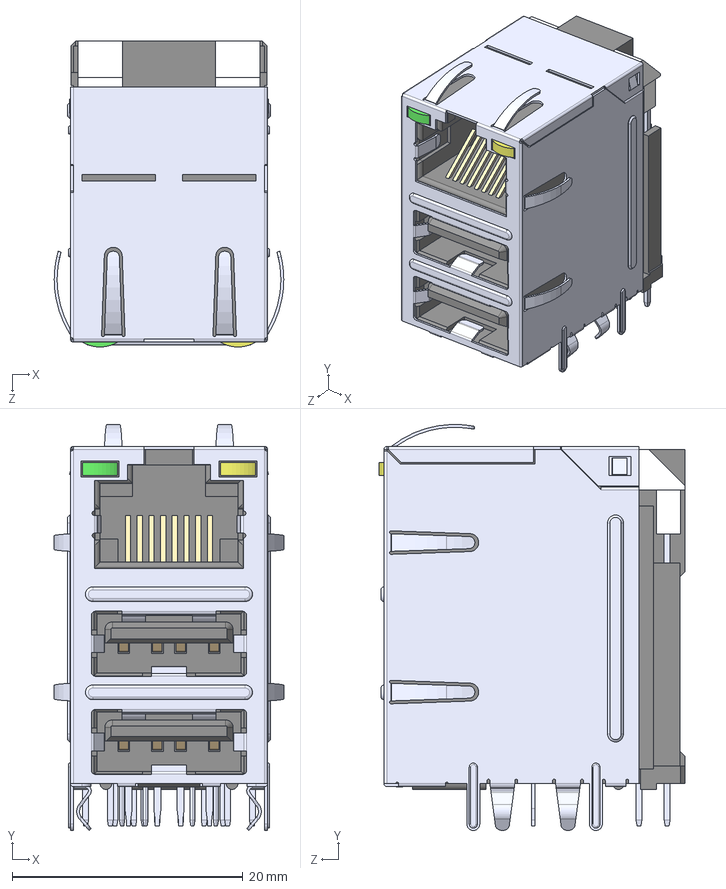
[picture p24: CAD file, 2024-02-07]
kicad/3dmodels/0862-1J1T-46A-F.STEP
19.9 x 35.2 x 26.5 mm

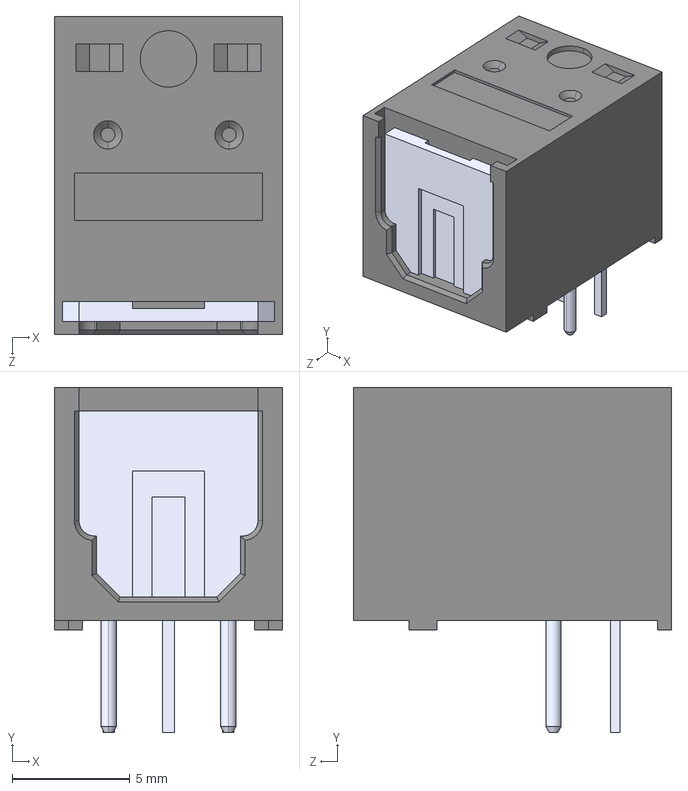
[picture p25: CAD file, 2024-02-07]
kicad/3dmodels/T10W--3DModel-STEP-56544.STEP
9.70 x 14.7 x 13.5 mm

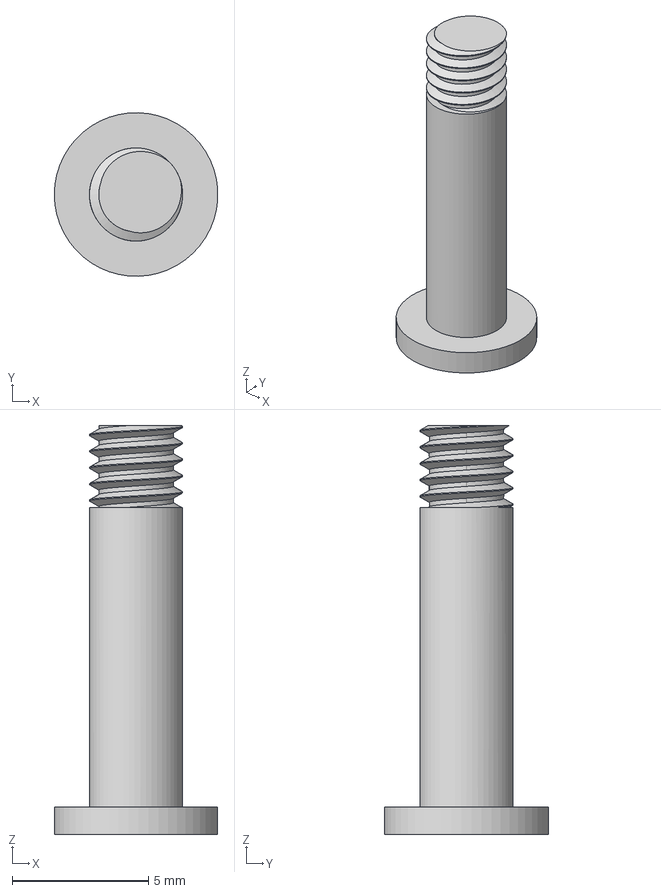
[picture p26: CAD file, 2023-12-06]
mechanical/fan_mount/fan_screw.step
5.99 x 6.00 x 15.0 mm

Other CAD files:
kicad/3dmodels/5176139.step
mechanical/fan_mount/fan_mount_nut.step
mechanical/fan_mount/fan_nut.step
kicad/3dmodels/JA33333-DA18-4F-combined.step
kicad/3dmodels/1734021-4.step
kicad/3dmodels/442060002.step
kicad/3dmodels/67800-8005.step
kicad/3dmodels/70543-0003.step

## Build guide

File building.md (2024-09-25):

# Building your own ITX-Llama

> **Note**  
> This document is still a work in progress.  
For feedback, suggestions, etc. - please add a post to the [Vogons thread][vogons-thread].

## BOM
There's a BOM file [here][bom], ready to be used with JLCPCB's assembly service.
In addition to the components that can be sourced through JLC/LCSC, you need to order a few extras elsewhere:
- Vortex86EX SOM - [DMP][som]
- Crystal CS4237B - Search for "cs4237b" on [eBay][ebay]
- ATTINY84A-PU - [DigiKey][digikey], [Mouser][mouser], etc

For programming the ATTiny, you need a hardware AVR programmer. There are plenty out there.

If you want emulated modem:
- D1 Mini v4.0.0 (ESP8266) - [AliExpress][d1mini]

[vogons-thread]: https://www.vogons.org/viewtopic.php?t=93480
[bom]: kicad/fabrication/ITX-Llama-v1revE-BOM.xlsx
[som]: https://shop.dmp.com.tw/INT/products/25
[ebay]: https://ebay.com
[digikey]: https://www.digikey.com/en/products/detail/microchip-technology/ATTINY84A-PU/2774082
[mouser]: https://www2.mouser.com/ProductDetail/Microchip-Technology/ATTINY84A-PU?qs=JVB2vxgwrww2b%2Fem%2FNzH9Q%3D%3D
[d1mini]: https://www.aliexpress.com/item/1005001621784437.html

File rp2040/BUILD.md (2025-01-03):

# Build

Get the Raspberry Pi Pico SDK version 1.5.1 and compiler:

```sh
sudo apt install cmake gcc-arm-none-eabi libnewlib-arm-none-eabi libstdc++-arm-none-eabi-newlib
git clone https://github.com/raspberrypi/pico-sdk
export PICO_SDK_PATH=/path/to/pico-sdk
cd $PICO_SDK_PATH
git checkout 1.5.1
git submodule update --init
```

Update to the latest TinyUSB release 0.17.0 and apply the dual USB patch:
```sh
cd $PICO_SDK_PATH/lib/tinyusb
git checkout 0.17.0
patch -p1 < /path/to/itxllama/rp2040/tinyusb-0.17.0-dualusb.patch
```

Generate the UF2 file:
```sh
cd /path/to/itxllama/rp2040
git submodule update --init
mkdir build
cd build
cmake ..
make
```

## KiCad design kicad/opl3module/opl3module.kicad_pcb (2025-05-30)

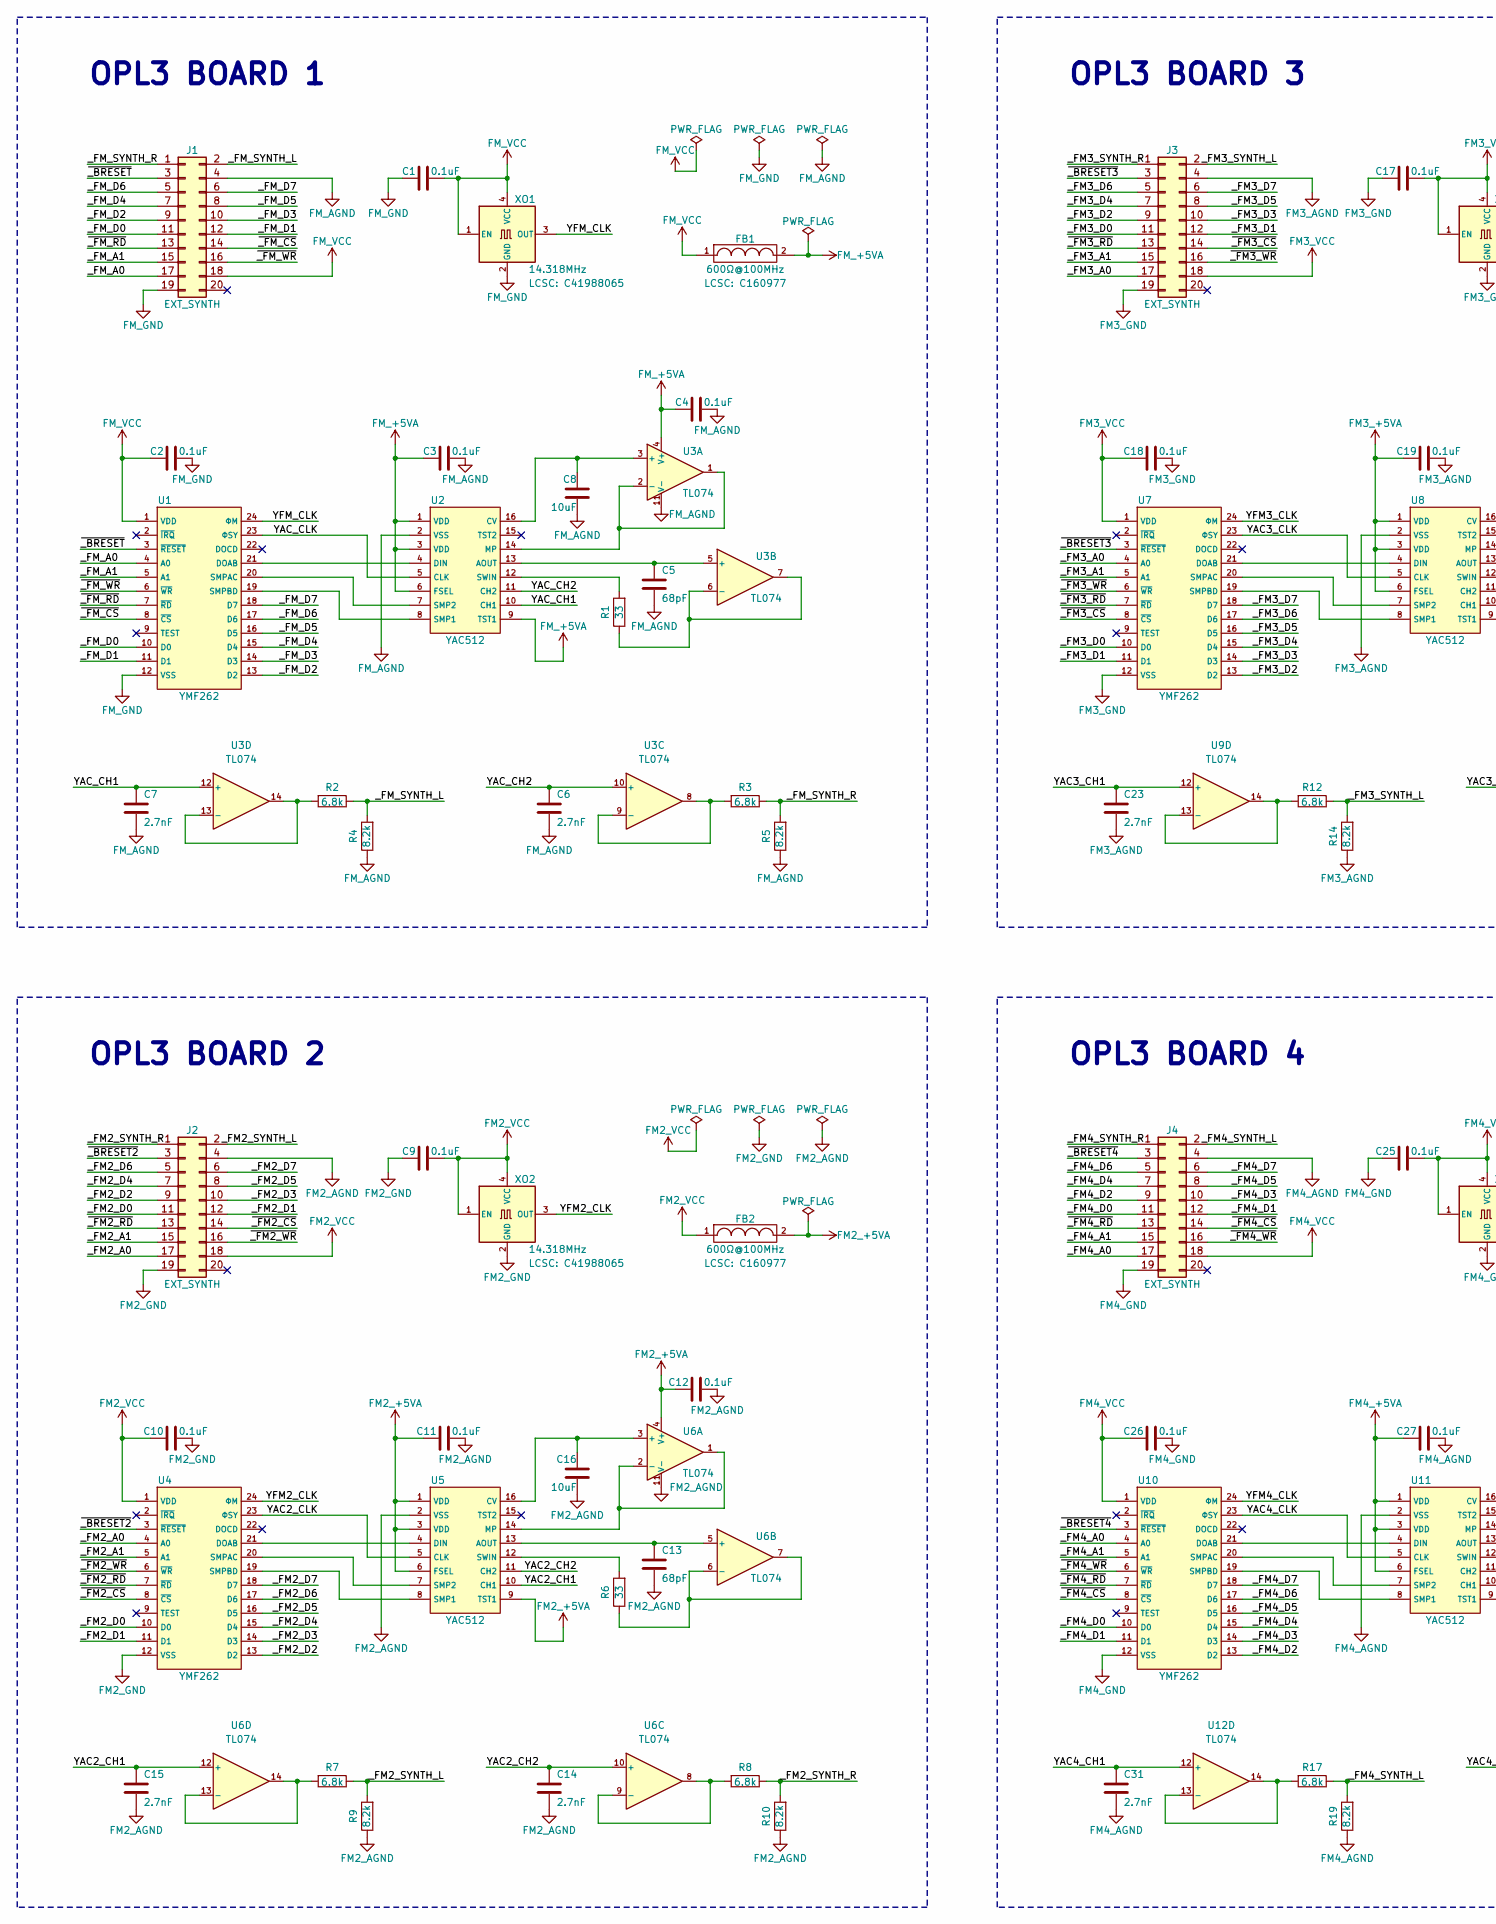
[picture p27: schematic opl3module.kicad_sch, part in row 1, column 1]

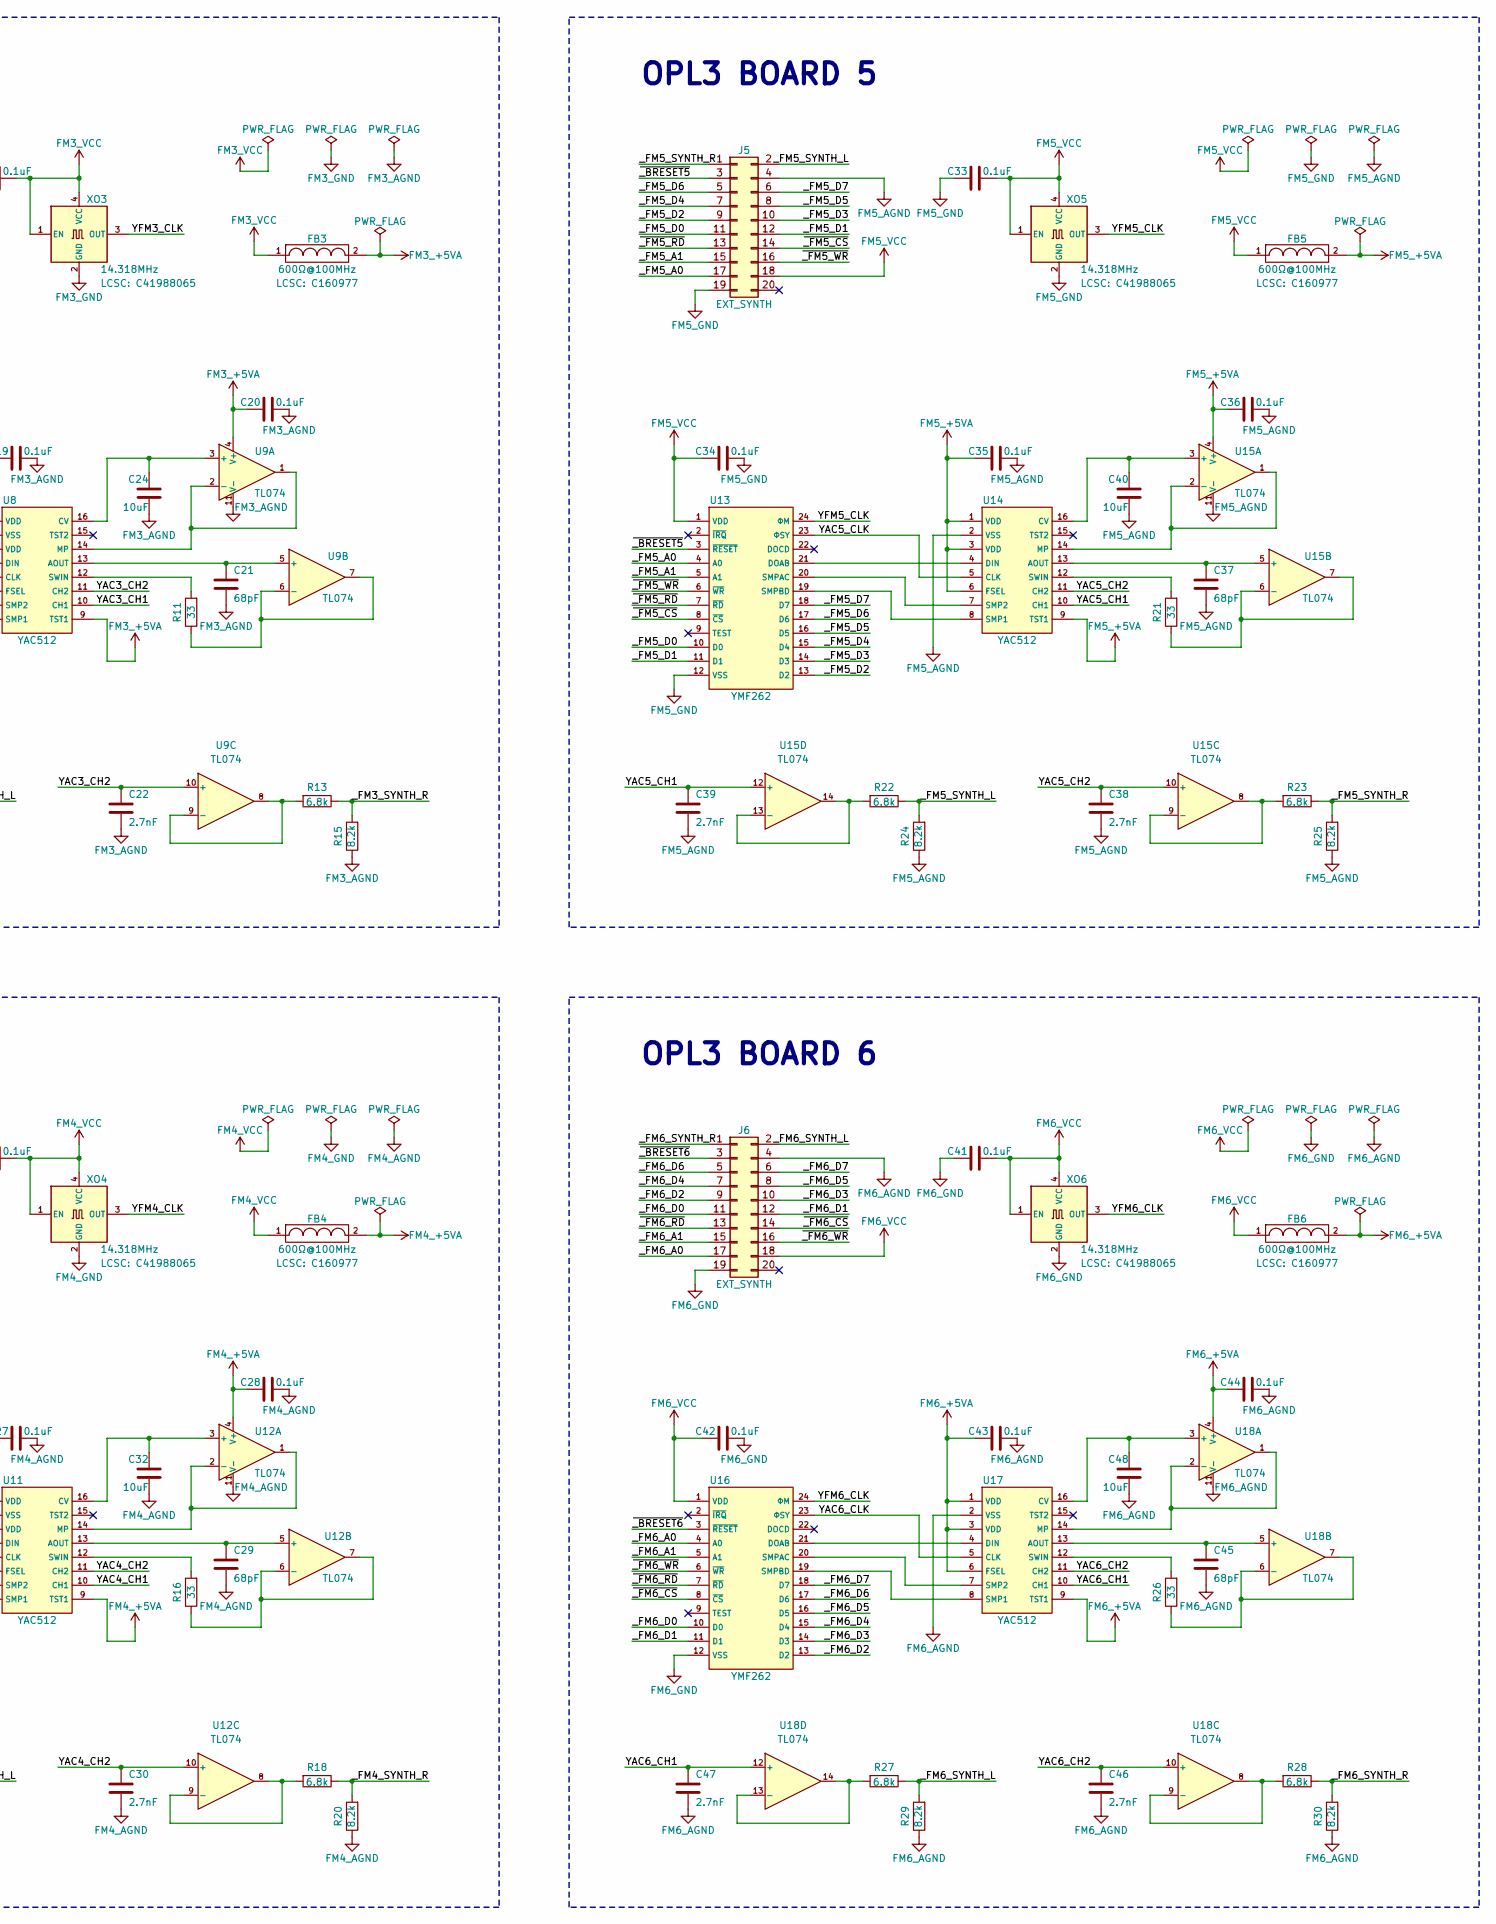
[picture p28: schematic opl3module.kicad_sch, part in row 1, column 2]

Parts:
C1, C2, C3, C4, C9, C10, C11, C12, C17, C18, C19, C20, C25, C26, C27, C28, C33, C34, C35, C36, C41, C42, C43, C44: 0.1uF; C_0402_1005Metric
C5, C13, C21, C29, C37, C45: 68pF; C_0402_1005Metric
C6, C7, C14, C15, C22, C23, C30, C31, C38, C39, C46, C47: 2.7nF; C_0603_1608Metric
C8, C16, C24, C32, C40, C48: 10uF; C_0603_1608Metric
FB1, FB2, FB3, FB4, FB5, FB6: 600Ω@100MHz; R_0402_1005Metric; LCSC C160977
J1, J2, J3, J4, J5, J6: EXT_SYNTH; P_CONN_02X10
R1, R6, R11, R16, R21, R26: 33; R_0402_1005Metric
R2, R3, R7, R8, R12, R13, R17, R18, R22, R23, R27, R28: 6.8k; R_0402_1005Metric
R4, R5, R9, R10, R14, R15, R19, R20, R24, R25, R29, R30: 8.2k; R_0402_1005Metric
U1, U4, U7, U10, U13, U16: YMF262; U_SOP-24_8.4x15.5mm_P1.27mm
U2, U5, U8, U11, U14, U17: YAC512; U_SOP-16_5.3x10.2mm_P1.27mm
U3, U6, U9, U12, U15, U18: TL074; U_SOIC-14_3.9x8.7mm_P1.27mm
XO1, XO2, XO3, XO4, XO5, XO6: 14.318MHz; XO_SMD7050; LCSC C41988065

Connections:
/YAC2_CH1: C15.1, U5.10 (CH1), U6.12 (+)
/YAC2_CH2: C14.1, U5.11 (CH2), U6.10 (+)
/YAC2_CLK: U4.23 (ΦSY), U5.5 (CLK)
/YAC3_CH1: C23.1, U8.10 (CH1), U9.12 (+)
/YAC3_CH2: C22.1, U8.11 (CH2), U9.10 (+)
/YAC3_CLK: U7.23 (ΦSY), U8.5 (CLK)
/YAC4_CH1: C31.1, U11.10 (CH1), U12.12 (+)
/YAC4_CH2: C30.1, U11.11 (CH2), U12.10 (+)
/YAC4_CLK: U10.23 (ΦSY), U11.5 (CLK)
/YAC5_CH1: C39.1, U14.10 (CH1), U15.12 (+)
/YAC5_CH2: C38.1, U14.11 (CH2), U15.10 (+)
/YAC5_CLK: U13.23 (ΦSY), U14.5 (CLK)
/YAC6_CH1: C47.1, U17.10 (CH1), U18.12 (+)
/YAC6_CH2: C46.1, U17.11 (CH2), U18.10 (+)
/YAC6_CLK: U16.23 (ΦSY), U17.5 (CLK)
/YAC_CH1: C7.1, U2.10 (CH1), U3.12 (+)
/YAC_CH2: C6.1, U2.11 (CH2), U3.10 (+)
/YAC_CLK: U1.23 (ΦSY), U2.5 (CLK)
/YFM2_CLK: U4.24 (ΦM), XO2.3 (OUT)
/YFM3_CLK: U7.24 (ΦM), XO3.3 (OUT)
/YFM4_CLK: U10.24 (ΦM), XO4.3 (OUT)
/YFM5_CLK: U13.24 (ΦM), XO5.3 (OUT)
/YFM6_CLK: U16.24 (ΦM), XO6.3 (OUT)
/YFM_CLK: U1.24 (ΦM), XO1.3 (OUT)
/_FM2_A0: J2.17, U4.4 (A0)
/_FM2_A1: J2.15, U4.5 (A1)
/_FM2_D0: J2.11, U4.10 (D0)
/_FM2_D1: J2.12, U4.11 (D1)
/_FM2_D2: J2.9, U4.13 (D2)
/_FM2_D3: J2.10, U4.14 (D3)
/_FM2_D4: J2.7, U4.15 (D4)
/_FM2_D5: J2.8, U4.16 (D5)
/_FM2_D6: J2.5, U4.17 (D6)
/_FM2_D7: J2.6, U4.18 (D7)
/_FM2_SYNTH_L: J2.2, R7.1, R9.2
/_FM2_SYNTH_R: J2.1, R8.1, R10.2
/_FM3_A0: J3.17, U7.4 (A0)
/_FM3_A1: J3.15, U7.5 (A1)
/_FM3_D0: J3.11, U7.10 (D0)
/_FM3_D1: J3.12, U7.11 (D1)
/_FM3_D2: J3.9, U7.13 (D2)
/_FM3_D3: J3.10, U7.14 (D3)
/_FM3_D4: J3.7, U7.15 (D4)
/_FM3_D5: J3.8, U7.16 (D5)
/_FM3_D6: J3.5, U7.17 (D6)
/_FM3_D7: J3.6, U7.18 (D7)
/_FM3_SYNTH_L: J3.2, R12.1, R14.2
/_FM3_SYNTH_R: J3.1, R13.1, R15.2
/_FM4_A0: J4.17, U10.4 (A0)
/_FM4_A1: J4.15, U10.5 (A1)
/_FM4_D0: J4.11, U10.10 (D0)
/_FM4_D1: J4.12, U10.11 (D1)
/_FM4_D2: J4.9, U10.13 (D2)
/_FM4_D3: J4.10, U10.14 (D3)
/_FM4_D4: J4.7, U10.15 (D4)
/_FM4_D5: J4.8, U10.16 (D5)
/_FM4_D6: J4.5, U10.17 (D6)
/_FM4_D7: J4.6, U10.18 (D7)
/_FM4_SYNTH_L: J4.2, R17.1, R19.2
/_FM4_SYNTH_R: J4.1, R18.1, R20.2
/_FM5_A0: J5.17, U13.4 (A0)
/_FM5_A1: J5.15, U13.5 (A1)
/_FM5_D0: J5.11, U13.10 (D0)
/_FM5_D1: J5.12, U13.11 (D1)
/_FM5_D2: J5.9, U13.13 (D2)
/_FM5_D3: J5.10, U13.14 (D3)
/_FM5_D4: J5.7, U13.15 (D4)
/_FM5_D5: J5.8, U13.16 (D5)
/_FM5_D6: J5.5, U13.17 (D6)
/_FM5_D7: J5.6, U13.18 (D7)
/_FM5_SYNTH_L: J5.2, R22.1, R24.2
/_FM5_SYNTH_R: J5.1, R23.1, R25.2
/_FM6_A0: J6.17, U16.4 (A0)
/_FM6_A1: J6.15, U16.5 (A1)
/_FM6_D0: J6.11, U16.10 (D0)
/_FM6_D1: J6.12, U16.11 (D1)
/_FM6_D2: J6.9, U16.13 (D2)
/_FM6_D3: J6.10, U16.14 (D3)
/_FM6_D4: J6.7, U16.15 (D4)
/_FM6_D5: J6.8, U16.16 (D5)
/_FM6_D6: J6.5, U16.17 (D6)
/_FM6_D7: J6.6, U16.18 (D7)
/_FM6_SYNTH_L: J6.2, R27.1, R29.2
/_FM6_SYNTH_R: J6.1, R28.1, R30.2
/_FM_A0: J1.17, U1.4 (A0)
/_FM_A1: J1.15, U1.5 (A1)
/_FM_D0: J1.11, U1.10 (D0)
/_FM_D1: J1.12, U1.11 (D1)
/_FM_D2: J1.9, U1.13 (D2)
/_FM_D3: J1.10, U1.14 (D3)
/_FM_D4: J1.7, U1.15 (D4)
/_FM_D5: J1.8, U1.16 (D5)
/_FM_D6: J1.5, U1.17 (D6)
/_FM_D7: J1.6, U1.18 (D7)
/_FM_SYNTH_L: J1.2, R2.1, R4.2
/_FM_SYNTH_R: J1.1, R3.1, R5.2
/~_BRESET2: J2.3, U4.3 (~RESET)
/~_BRESET3: J3.3, U7.3 (~RESET)
/~_BRESET4: J4.3, U10.3 (~RESET)
/~_BRESET5: J5.3, U13.3 (~RESET)
/~_BRESET6: J6.3, U16.3 (~RESET)
/~_BRESET: J1.3, U1.3 (~RESET)
/~_FM2_CS: J2.14, U4.8 (~CS)
/~_FM2_RD: J2.13, U4.7 (~RD)
/~_FM2_WR: J2.16, U4.6 (~WR)
/~_FM3_CS: J3.14, U7.8 (~CS)
/~_FM3_RD: J3.13, U7.7 (~RD)
/~_FM3_WR: J3.16, U7.6 (~WR)
/~_FM4_CS: J4.14, U10.8 (~CS)
/~_FM4_RD: J4.13, U10.7 (~RD)
/~_FM4_WR: J4.16, U10.6 (~WR)
/~_FM5_CS: J5.14, U13.8 (~CS)
/~_FM5_RD: J5.13, U13.7 (~RD)
/~_FM5_WR: J5.16, U13.6 (~WR)
/~_FM6_CS: J6.14, U16.8 (~CS)
/~_FM6_RD: J6.13, U16.7 (~RD)
/~_FM6_WR: J6.16, U16.6 (~WR)
/~_FM_CS: J1.14, U1.8 (~CS)
/~_FM_RD: J1.13, U1.7 (~RD)
/~_FM_WR: J1.16, U1.6 (~WR)
FM2_+5VA: C11.2, C12.2, FB2.2, U5.1 (VDD), U5.3 (VDD), U5.6 (FSEL), U5.9 (TST1), U6.4 (V+)
FM2_AGND: C11.1, C12.1, C13.2, C14.2, C15.2, C16.1, J2.4, R9.1, R10.1, U5.2 (VSS), U6.11 (V-)
FM2_GND: C9.2, C10.1, J2.19, U4.12 (VSS), XO2.2 (GND)
FM2_VCC: C9.1, C10.2, FB2.1, J2.18, U4.1 (VDD), XO2.1 (EN), XO2.4 (VCC)
FM3_+5VA: C19.2, C20.2, FB3.2, U8.1 (VDD), U8.3 (VDD), U8.6 (FSEL), U8.9 (TST1), U9.4 (V+)
FM3_AGND: C19.1, C20.1, C21.2, C22.2, C23.2, C24.1, J3.4, R14.1, R15.1, U8.2 (VSS), U9.11 (V-)
FM3_GND: C17.2, C18.1, J3.19, U7.12 (VSS), XO3.2 (GND)
FM3_VCC: C17.1, C18.2, FB3.1, J3.18, U7.1 (VDD), XO3.1 (EN), XO3.4 (VCC)
FM4_+5VA: C27.2, C28.2, FB4.2, U11.1 (VDD), U11.3 (VDD), U11.6 (FSEL), U11.9 (TST1), U12.4 (V+)
FM4_AGND: C27.1, C28.1, C29.2, C30.2, C31.2, C32.1, J4.4, R19.1, R20.1, U11.2 (VSS), U12.11 (V-)
FM4_GND: C25.2, C26.1, J4.19, U10.12 (VSS), XO4.2 (GND)
FM4_VCC: C25.1, C26.2, FB4.1, J4.18, U10.1 (VDD), XO4.1 (EN), XO4.4 (VCC)
FM5_+5VA: C35.2, C36.2, FB5.2, U14.1 (VDD), U14.3 (VDD), U14.6 (FSEL), U14.9 (TST1), U15.4 (V+)
FM5_AGND: C35.1, C36.1, C37.2, C38.2, C39.2, C40.1, J5.4, R24.1, R25.1, U14.2 (VSS), U15.11 (V-)
FM5_GND: C33.2, C34.1, J5.19, U13.12 (VSS), XO5.2 (GND)
FM5_VCC: C33.1, C34.2, FB5.1, J5.18, U13.1 (VDD), XO5.1 (EN), XO5.4 (VCC)
FM6_+5VA: C43.2, C44.2, FB6.2, U17.1 (VDD), U17.3 (VDD), U17.6 (FSEL), U17.9 (TST1), U18.4 (V+)
FM6_AGND: C43.1, C44.1, C45.2, C46.2, C47.2, C48.1, J6.4, R29.1, R30.1, U17.2 (VSS), U18.11 (V-)
FM6_GND: C41.2, C42.1, J6.19, U16.12 (VSS), XO6.2 (GND)
FM6_VCC: C41.1, C42.2, FB6.1, J6.18, U16.1 (VDD), XO6.1 (EN), XO6.4 (VCC)
FM_+5VA: C3.2, C4.2, FB1.2, U2.1 (VDD), U2.3 (VDD), U2.6 (FSEL), U2.9 (TST1), U3.4 (V+)
FM_AGND: C3.1, C4.1, C5.2, C6.2, C7.2, C8.1, J1.4, R4.1, R5.1, U2.2 (VSS), U3.11 (V-)
FM_GND: C1.2, C2.1, J1.19, U1.12 (VSS), XO1.2 (GND)
FM_VCC: C1.1, C2.2, FB1.1, J1.18, U1.1 (VDD), XO1.1 (EN), XO1.4 (VCC)
unnamed: U1.21 (DOAB), U2.4 (DIN)
unnamed: U1.20 (SMPAC), U2.7 (SMP2)
unnamed: U1.19 (SMPBD), U2.8 (SMP1)
unnamed: C5.1, U2.13 (AOUT), U3.5 (+)
unnamed: C8.2, U2.16 (CV), U3.3 (+)
unnamed: U2.14 (MP), U3.1, U3.2 (-)
unnamed: R1.2, U2.12 (SWIN)
unnamed: R1.1, U3.6 (-), U3.7
unnamed: R3.2, U3.8, U3.9 (-)
unnamed: R2.2, U3.13 (-), U3.14
unnamed: U4.21 (DOAB), U5.4 (DIN)
unnamed: U4.20 (SMPAC), U5.7 (SMP2)
unnamed: U4.19 (SMPBD), U5.8 (SMP1)
unnamed: C13.1, U5.13 (AOUT), U6.5 (+)
unnamed: C16.2, U5.16 (CV), U6.3 (+)
unnamed: U5.14 (MP), U6.1, U6.2 (-)
unnamed: R6.2, U5.12 (SWIN)
unnamed: R6.1, U6.6 (-), U6.7
unnamed: R8.2, U6.8, U6.9 (-)
unnamed: R7.2, U6.13 (-), U6.14
unnamed: U7.21 (DOAB), U8.4 (DIN)
unnamed: U7.20 (SMPAC), U8.7 (SMP2)
unnamed: U7.19 (SMPBD), U8.8 (SMP1)
unnamed: C21.1, U8.13 (AOUT), U9.5 (+)
unnamed: C24.2, U8.16 (CV), U9.3 (+)
unnamed: U8.14 (MP), U9.1, U9.2 (-)
unnamed: R11.2, U8.12 (SWIN)
unnamed: R11.1, U9.6 (-), U9.7
unnamed: R13.2, U9.8, U9.9 (-)
unnamed: R12.2, U9.13 (-), U9.14
unnamed: U10.21 (DOAB), U11.4 (DIN)
unnamed: U10.20 (SMPAC), U11.7 (SMP2)
unnamed: U10.19 (SMPBD), U11.8 (SMP1)
unnamed: C29.1, U11.13 (AOUT), U12.5 (+)
unnamed: C32.2, U11.16 (CV), U12.3 (+)
unnamed: U11.14 (MP), U12.1, U12.2 (-)
unnamed: R16.2, U11.12 (SWIN)
unnamed: R16.1, U12.6 (-), U12.7
unnamed: R18.2, U12.8, U12.9 (-)
unnamed: R17.2, U12.13 (-), U12.14
unnamed: U13.21 (DOAB), U14.4 (DIN)
unnamed: U13.20 (SMPAC), U14.7 (SMP2)
unnamed: U13.19 (SMPBD), U14.8 (SMP1)
unnamed: C37.1, U14.13 (AOUT), U15.5 (+)
unnamed: C40.2, U14.16 (CV), U15.3 (+)
unnamed: U14.14 (MP), U15.1, U15.2 (-)
unnamed: R21.2, U14.12 (SWIN)
unnamed: R21.1, U15.6 (-), U15.7
unnamed: R23.2, U15.8, U15.9 (-)
unnamed: R22.2, U15.13 (-), U15.14
unnamed: U16.21 (DOAB), U17.4 (DIN)
unnamed: U16.20 (SMPAC), U17.7 (SMP2)
unnamed: U16.19 (SMPBD), U17.8 (SMP1)
unnamed: C45.1, U17.13 (AOUT), U18.5 (+)
unnamed: C48.2, U17.16 (CV), U18.3 (+)
unnamed: U17.14 (MP), U18.1, U18.2 (-)
unnamed: R26.2, U17.12 (SWIN)
unnamed: R26.1, U18.6 (-), U18.7
unnamed: R28.2, U18.8, U18.9 (-)
unnamed: R27.2, U18.13 (-), U18.14

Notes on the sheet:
OPL3 BOARD 3
OPL3 BOARD 1
OPL3 BOARD 2
OPL3 BOARD 5
OPL3 BOARD 4
OPL3 BOARD 6

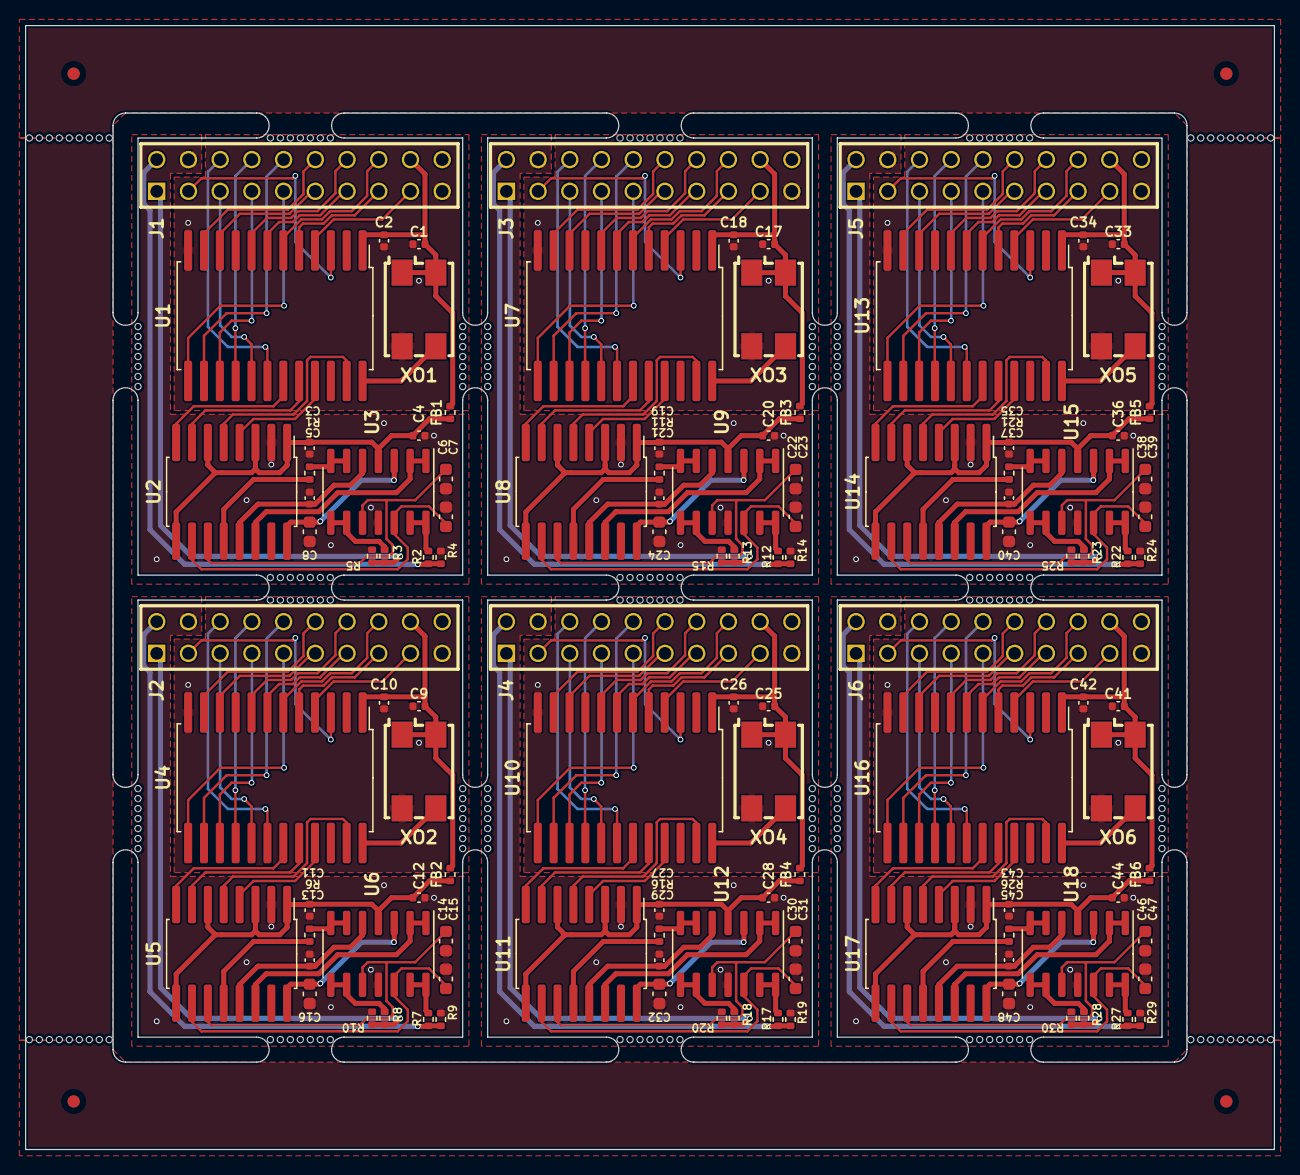
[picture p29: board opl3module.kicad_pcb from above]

Board: 4 copper layers, 100.0 x 90.0 mm, 114 parts (0 on the bottom side), 204 nets.

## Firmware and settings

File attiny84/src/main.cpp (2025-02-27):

#include <Arduino.h>
#include <EEPROM.h>
#include <TinyWireS.h>

#define PWR_LED_PIN   PA0
#define HDD_LED_PIN   PA1
#define RED_PIN       PA2
#define GREEN_PIN     PA3
#define CLICK_PIN     PA5
#define CLICK_PIN_A   PIN_PA5
#define ON_PIN        PB3
#define SD_CMD_PIN    PB2
#define SD_CMD_PCI    PCINT10
#define SD_DAT0_PIN   PA7
#define SD_DAT0_PCI   PCINT7

#define I2C_SLAVE_ADDRESS 0x20

#define I2C_LED_ENABLED_REG     0x01  // RW - 0x00 - disabled, 0x01 - enabled
#define I2C_LED_INTENSITY_REG   0x02  // RW - 0x00-0xFF, 0-100% intensity

#define I2C_CLICK_ENABLED_REG   0x11  // RW - 0x00 - disabled, 0x01 - enabled

#define EEPROM_LED_VALUES_MODIFIED_ADDRESS    (int)0x00
#define EEPROM_LED_ENABLED_ADDRESS            (int)0x01
#define EEPROM_LED_INTENSITY_ADDRESS          (int)0x02

#define EEPROM_CLICK_VALUES_MODIFIED_ADDRESS  (int)0x10
#define EEPROM_CLICK_ENABLED_ADDRESS          (int)0x11

#define EEPROM_MODIFIED_MAGIC_BYTE 0x55

#define LED_DEFAULT_ENABLED     1
#define LED_DEFAULT_INTENSITY   64   // 25% of 255
#define CLICK_DEFAULT_ENABLED   1
#define CLICK_DEFAULT_FREQ      30   // Hz
#define CLICK_DEFAULT_DURATION  20   // ms
#define CLICK_DEFAULT_PAUSE     3    // ms

#define LED_FREQ 100 // Hz

enum ActState : uint8_t { ACT_IDLE, ACT_ON, ACT_OFF };

enum LEDState : uint8_t { LED_OFF, LED_ON };

volatile uint8_t sd_act = 0;

ActState act_state                = ACT_IDLE;
unsigned long act_timer_start     = 0;
unsigned long click_freq          = CLICK_DEFAULT_FREQ;            // Hz
unsigned long click_timer_period  = CLICK_DEFAULT_DURATION * 1000; // microseconds
unsigned long click_pause         = CLICK_DEFAULT_PAUSE * 1000;    // microseconds

unsigned long led_cycle_length    = 1000000 / LED_FREQ;            // microseconds

LEDState red_led_state              = LED_OFF;
unsigned long red_led_timer_start   = 0;
uint8_t red_led_pwm_duty            = LED_DEFAULT_INTENSITY;
LEDState green_led_state            = LED_OFF;
unsigned long green_led_timer_start = 0;
uint8_t green_led_pwm_duty          = LED_DEFAULT_INTENSITY;

uint8_t global_led_enabled          = LED_DEFAULT_ENABLED;
uint8_t global_click_enabled        = CLICK_DEFAULT_ENABLED;

uint8_t pwr_led_on = 0;
uint8_t hdd_led_on = 0;

volatile uint8_t i2c_received_byte = 0xFF;
uint8_t i2c_reg = 0xFF;

ISR(PCINT0_vect) {
  sd_act = 1;
}

// ISR(PCINT1_vect) {
//   sd_act = 1;
// }

void receiveEvent(uint8_t howMany) {
  if (howMany != 1) return;
  i2c_received_byte = TinyWireS.receive();
}

void requestEvent(void) {
  if (i2c_reg == 0xFF) { // can't read from register without setting its address first
    TinyWireS.send(0x00);
    return;
  }
  switch (i2c_reg) {
    case I2C_LED_ENABLED_REG: {
      TinyWireS.send(global_led_enabled);
      break;
    }
    case I2C_LED_INTENSITY_REG: {
      TinyWireS.send(red_led_pwm_duty);
      break;
    }
    case I2C_CLICK_ENABLED_REG: {
      TinyWireS.send(global_click_enabled);
      break;
    }
    default: {
      TinyWireS.send(0x00);
      break;
    }
  }
  i2c_reg = 0xFF;
}

void processAct(unsigned long micros, uint8_t act) {
  switch (act_state) {
    case ACT_IDLE: {
      if (act) {
        act_timer_start = micros;
        if (global_click_enabled) {
          tone(CLICK_PIN_A, click_freq);
        }
        act_state = ACT_ON;
      }
      break;
    }
    case ACT_ON: {
      if ((micros - act_timer_start) > click_timer_period) {
        noTone(CLICK_PIN_A);
        act_timer_start = micros;
        act_state = ACT_OFF;
      }
      break;
    }
    case ACT_OFF: {
      if ((micros - act_timer_start) > click_pause) {
        act_state = ACT_IDLE;
      }
    }
  }
}

void processLEDs(unsigned long micros) {

  uint8_t has_power = PINB & _BV(ON_PIN);
  uint8_t process_red = !has_power || act_state == ACT_ON;
  uint8_t process_green = has_power;

  if (has_power && global_led_enabled) {
    if (!pwr_led_on) {
      PORTA |= _BV(PWR_LED_PIN);
      pwr_led_on = 1;
    }
  } else {
    if (pwr_led_on) {
      PORTA &= ~_BV(PWR_LED_PIN);
      pwr_led_on = 0;
    }
  }

  if (act_state == ACT_ON && global_led_enabled) {
    if (!hdd_led_on) {
      PORTA |= _BV(HDD_LED_PIN);
      hdd_led_on = 1;
    }
  } else {
    if (hdd_led_on) {
      PORTA &= ~_BV(HDD_LED_PIN);
      hdd_led_on = 0;
    }
  }

  if (process_red) {
    if (!process_green) PORTA &= ~_BV(GREEN_PIN);
    unsigned long on_time = led_cycle_length * red_led_pwm_duty / 0xFF;
    unsigned long off_time = led_cycle_length - on_time;
    switch (red_led_state) {
      case LED_OFF: {
        if ((micros - red_led_timer_start) > off_time) {
          if (global_led_enabled) {
            PORTA |= _BV(RED_PIN);
          }
          red_led_timer_start = micros;
          red_led_state = LED_ON;
        }
        break;
      }
      case LED_ON: {
        if ((micros - red_led_timer_start) > on_time) {
          PORTA &= ~_BV(RED_PIN);
          red_led_timer_start = micros;
          red_led_state = LED_OFF;
        }
        break;
      }
    }
  }

  if (process_green) {
    if (!process_red) PORTA &= ~_BV(RED_PIN);
    unsigned long on_time = led_cycle_length * green_led_pwm_duty / 0xFF;
    unsigned long off_time = led_cycle_length - on_time;
    switch (green_led_state) {
      case LED_OFF: {
        if ((micros - green_led_timer_start) > off_time) {
          if (global_led_enabled) {
            PORTA |= _BV(GREEN_PIN);
          }
          green_led_timer_start = micros;
          green_led_state = LED_ON;
        }
        break;
      }
      case LED_ON: {
        if ((micros - green_led_timer_start) > on_time) {
          PORTA &= ~_BV(GREEN_PIN);
          green_led_timer_start = micros;
          green_led_state = LED_OFF;
        }
        break;
      }
    }
  }
}

void processI2C(void) {
  uint8_t byte = i2c_received_byte;
  if (i2c_reg == 0xFF) { // no register set, hopefully the received byte is a call to set the address
    switch (byte) {
      case I2C_LED_ENABLED_REG: {
        i2c_reg = I2C_LED_ENABLED_REG;
        break;
      }
      case I2C_LED_INTENSITY_REG: {
        i2c_reg = I2C_LED_INTENSITY_REG;
        break;
      }
      case I2C_CLICK_ENABLED_REG: {
        i2c_reg = I2C_CLICK_ENABLED_REG;
        break;
      }
      default: break;
    }
  } else { // call to write to register
    switch (i2c_reg) {
      case I2C_LED_ENABLED_REG: {
        global_led_enabled = byte;
        EEPROM.update(EEPROM_LED_ENABLED_ADDRESS, byte);
        delay(5);
        break;
      }
      case I2C_LED_INTENSITY_REG: {
        red_led_pwm_duty = byte;
        green_led_pwm_duty = byte;
        EEPROM.update(EEPROM_LED_INTENSITY_ADDRESS, byte);
        delay(5);
        break;
      }
      case I2C_CLICK_ENABLED_REG: {
        global_click_enabled = byte;
        EEPROM.update(EEPROM_CLICK_ENABLED_ADDRESS, byte);
        delay(5);
        break;
      }
      default: break;
    }
    i2c_reg = 0xFF;
  }
  i2c_received_byte = 0xFF;
}

void load_eeprom_values(void) {
  uint8_t led_values_modified = EEPROM.read(EEPROM_LED_VALUES_MODIFIED_ADDRESS);
  delay(5);
  if (led_values_modified == EEPROM_MODIFIED_MAGIC_BYTE) {
    global_led_enabled = EEPROM.read(EEPROM_LED_ENABLED_ADDRESS);
    delay(5);
    uint8_t led_intensity = EEPROM.read(EEPROM_LED_INTENSITY_ADDRESS);
    delay(5);
    red_led_pwm_duty = led_intensity;
    green_led_pwm_duty = led_intensity;
  } else {
    EEPROM.update(EEPROM_LED_ENABLED_ADDRESS, LED_DEFAULT_ENABLED);
    delay(5);
    EEPROM.update(EEPROM_LED_INTENSITY_ADDRESS, LED_DEFAULT_INTENSITY);
    delay(5);
    EEPROM.update(EEPROM_LED_VALUES_MODIFIED_ADDRESS, EEPROM_MODIFIED_MAGIC_BYTE);
    delay(5);
  }

  uint8_t click_values_modified = EEPROM.read(EEPROM_CLICK_VALUES_MODIFIED_ADDRESS);
  delay(5);
  if (click_values_modified == EEPROM_MODIFIED_MAGIC_BYTE) {
    global_click_enabled = EEPROM.read(EEPROM_CLICK_ENABLED_ADDRESS);
    delay(5);
  } else {
    EEPROM.update(EEPROM_CLICK_ENABLED_ADDRESS, CLICK_DEFAULT_ENABLED);
    delay(5);
    EEPROM.update(EEPROM_CLICK_VALUES_MODIFIED_ADDRESS, EEPROM_MODIFIED_MAGIC_BYTE);
    delay(5);
  }
}

void setup() {
  DDRA &= ~_BV(SD_DAT0_PIN); // define as input
  DDRA |= _BV(PWR_LED_PIN) | // define as outputs
          _BV(HDD_LED_PIN) |
          _BV(RED_PIN)     |
          _BV(GREEN_PIN)   |
          _BV(CLICK_PIN);
  PORTA |= _BV(SD_DAT0_PIN); // pull-up

  DDRB &= ~(_BV(ON_PIN) | _BV(SD_CMD_PIN)); // define as inputs
  PORTB |= _BV(ON_PIN) | _BV(SD_CMD_PIN); // pull-up

  load_eeprom_values();

  // init interrupt
  cli();
  GIMSK = _BV(PCIE0);
  //GIMSK |= _BV(PCIE0) | _BV(PCIE1);
  PCMSK0 = _BV(SD_DAT0_PCI);
  //PCMSK1 |= _BV(SD_CMD_PCI);
  sei();

  TinyWireS.begin(I2C_SLAVE_ADDRESS);
  TinyWireS.onReceive(receiveEvent);
  TinyWireS.onRequest(requestEvent);
}

void loop() {
  TinyWireS_stop_check();
  if (i2c_received_byte != 0xFF) {
    processI2C();
  }
  unsigned long micros_now = micros();
  uint8_t act = sd_act;
  cli();
  sd_act = 0;
  sei();
  processAct(micros_now, act);
  processLEDs(micros_now);
}

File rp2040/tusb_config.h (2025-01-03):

/*
 * The MIT License (MIT)
 *
 * Copyright (c) 2019 Ha Thach (tinyusb.org)
 *
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
 */

#ifndef _TUSB_CONFIG_H_
#define _TUSB_CONFIG_H_

#ifdef __cplusplus
 extern "C" {
#endif

//--------------------------------------------------------------------
// Common Configuration
//--------------------------------------------------------------------

#define CFG_TUSB_MCU          OPT_MCU_RP2040
#define CFG_TUSB_OS           OPT_OS_PICO

// Enable Host stack
#define CFG_TUH_ENABLED       1
#define CFG_TUH_RPI_PIO_USB   1
#define CFG_TUH_RPI_DUAL_USB  1
#define BOARD_TUH_RHPORT      0
#define CFG_TUSB_RHPORT0_MODE (OPT_MODE_HOST | OPT_MODE_FULL_SPEED)
#define CFG_TUSB_RHPORT1_MODE (OPT_MODE_HOST | OPT_MODE_FULL_SPEED)

// RHPort max operational speed can defined by board.mk
#ifndef BOARD_TUH_MAX_SPEED
#define BOARD_TUH_MAX_SPEED   OPT_MODE_DEFAULT_SPEED
#endif

// Default is max speed that hardware controller could support with on-chip PHY
#define CFG_TUH_MAX_SPEED     BOARD_TUH_MAX_SPEED

#ifndef CFG_TUH_MEM_SECTION
#define CFG_TUH_MEM_SECTION
#endif

#ifndef CFG_TUH_MEM_ALIGN
#define CFG_TUH_MEM_ALIGN     __attribute__ ((aligned(4)))
#endif

//--------------------------------------------------------------------
// Driver Configuration
//--------------------------------------------------------------------

// Size of buffer to hold descriptors and other data used for enumeration
#define CFG_TUH_ENUMERATION_BUFSIZE 256

#define CFG_TUH_HUB                 2 // number of supported hubs
#define CFG_TUH_HID                 (4*CFG_TUH_DEVICE_MAX) // typical keyboard + mouse device can have 3-4 HID interfaces

// max device support (excluding hub device): 1 hub typically has 4 ports
#define CFG_TUH_DEVICE_MAX          (3*CFG_TUH_HUB + 1)

//------------- HID -------------//
#define CFG_TUH_HID_EPIN_BUFSIZE    128
#define CFG_TUH_HID_EPOUT_BUFSIZE   128

#ifdef __cplusplus
 }
#endif

#endif /* _TUSB_CONFIG_H_ */

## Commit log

2023-12-06 add win98 drivers
2023-12-06 add fan mount 3d models
    [fan_mount_frame.step, fan_mount_nut.step, fan_nut.step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]
2023-12-06 add fan mount description file
2023-12-06 add fan mount image, update description
2023-12-08 update drivers, documentation
2024-02-07 add kicad project
    [0862-1J1T-46A-F.STEP, 1-5145154-2.step, 1734021-4.step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]
2024-05-10 add opl3 kicad project
    [opl3module-BOM.xlsx, opl3module.kicad_pcb, opl3module.kicad_sch]
2024-05-19 Update platformio.ini
    Adding hfuse lfuse and efuse settings as well as Arduino ISP programming
2024-07-16 add pick and place file
    [ITX-Llama-v1revE-all-pos.xlsx]
2024-09-25 update readme, bom
    [ITX-Llama-v1revE-BOM.xlsx]
2024-11-16 correct GPIO for USB port
    [main.c]
2024-11-20 report mode for every device
2025-05-30 Update Kicad project for rev.F
    [ITX-Llama-B_Cu.gbl, ITX-Llama-B_Mask.gbs, ITX-Llama-B_Paste.gbp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]

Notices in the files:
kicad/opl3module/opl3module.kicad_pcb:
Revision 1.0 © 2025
